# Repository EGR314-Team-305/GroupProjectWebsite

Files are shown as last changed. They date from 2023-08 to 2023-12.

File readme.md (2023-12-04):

---
title: Home 
---
# Home Room Weather Control System

EGR314 Fall 2023  
Professor Nichols  
Team 305  
Members:    
Diego Rodriguez, Uriah Villa, Jack Windle, Nicholas Dunn

<p align="center" width="100%">
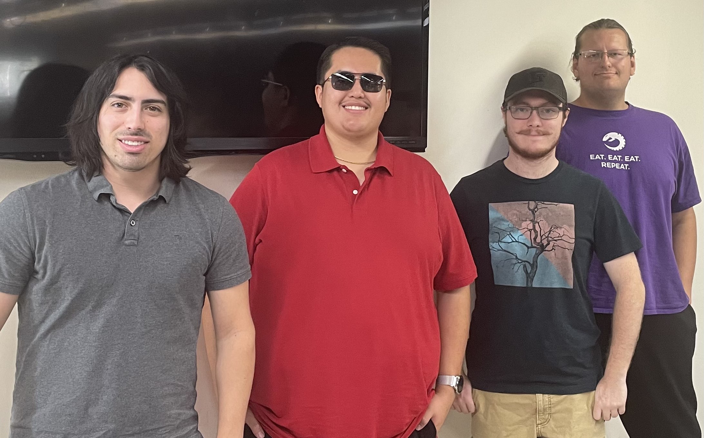
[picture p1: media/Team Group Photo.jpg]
      
</p>

image caption

# Table of Contents
* [Introduction](https://egr314-team-305.github.io/Team305.github.io/#introduction-team-305-semester-project)
* [Team Organization](https://egr314-team-305.github.io/Team305.github.io/#team-organization)
* [User Needs, Benchmarking and Reuirements](https://egr314-team-305.github.io/Team305.github.io/#user-needs-benchmarking-and-requirements)
* [Design Ideation and Final Selected Design](https://egr314-team-305.github.io/Team305.github.io/#design-ideation-and-final-design-selection)
* [Block Diagram](https://egr314-team-305.github.io/Team305.github.io/#block-diagram)
* [Component and Microcontroller Selection](https://egr314-team-305.github.io/Team305.github.io/#component-and-microcontroller-selection)
* [Hardware and Software Implemetation](https://egr314-team-305.github.io/Team305.github.io/#hardware-and-software-implementation)
* [System Verification and Final Presentation](https://egr314-team-305.github.io/Team305.github.io/#system-verification-and-final-presentation)
* [Lessons Learned](https://egr314-team-305.github.io/Team305.github.io/#lessons-learned)
* [Recommendations for Future Students](https://egr314-team-305.github.io/Team305.github.io/#recommendations-for-future-students)
* [Appendix](https://egr314-team-305.github.io/Team305.github.io/#appendix)

## Introduction: Team 305 Semester Project   
  With entering another project based class comes a semester project. For this project, we need to create a custom weather based system that includes multiple sensors and electronical communication. For communication aspects, we intend to use ESP32 two way WIFI communication that we will be taught in class. This will allow the user to view variable data produced by the final product we intend to create. Additional sensors for this project include motion, light, humidity, air pressure, temperature, and many more. We decided to go with light and temperature, as it fits with the project idea that will be stated below. Finally, we will need a motor and motor controller, functioning based on data given by the rest of the system.
  
  Conisidering the part requirements listed above, we decided to make a Home Room Weather Control System. This device will open and close window blinds depending on internal/external factors, light and temperature. The motor will control the blinds, and at what speed they move.
  
## Team Organization

 Our team needs to be organized in such a way that we can effectivly work together and best utilize each of our strengths.  We have defined what each member should be accountable for and how we will work together.  We wish to better ourselves and learn more about the detailed creation of subsystems and circuit boards. 
 
 In order to acomplish this, we devised roles, tasks and responsibilities for each of us to fulfill during the course of the semester. Greater details of this team formation process can be found on our [Team Organization](/Team-Organization.md) page.

## User Needs, Benchmarking, and Requirements  
  When deciding upon which ideals are most important to the customer, we utilized a process similar to reverse engineering. We first collected multiple items similar to our desired project idea, and researched information on them. This allowed us to discover many quailities about the products, such as price, vendor, and many positive and negative reviews about each one. Creating Jamboards after this allowed us to discover similarities about each item that we didn't think about. It was a very interesting [process](/UNBR.md) which took us longer than expected.

## Design Ideation and Final Design Selection 

  After we completed our user needs, we brainstormed any ideas we could think of that complies with our necessary measures. This landed us with three results. The third result we thought about was an automated door opener. Second was a temperature and light controlled fan, which would turn on when it's too hot or lights turn on. Our final design, which is what we chose, is a Home Room Weather Control System. This chosen design would operate window blinds based on external and internal conditions. If it's too bright, blinds close through the use of a motor controlled by the system. If it's too hot inside, it will close as well. If the room is cold, then the blinds will be opened, if external conditions meet specified criteria. Full details can be found on our [Design Ideation](/DIFDS.md) page.
  
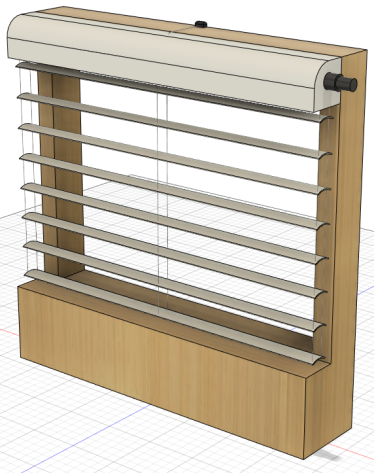
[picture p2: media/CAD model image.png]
image caption
  

## Block Diagram

  With figuring out what project we were going to work on came the process of brainstorming the workflow of the circuit we are creating. Figuring out what we would be using and listing how it would connect with eachother was the primary focus of this portion of the project. Aiming to create a full [Block Diagram](/BD.md) would allow us to visually represent the circuit board in a clear and easy to understand form. 
  
## Component and Microcontroller Selection  

  Once we had a plan for how the subsystems would interact with the main microcontroller, we had to decide on which parts we would utilize. For this process we researched our individual systems and discovered three pieces that would fulfill project parameters. Once this step had been completed, we selected the best of the three options to order, allowing us to finally choose all of our components...Well, most of them.

  After choosing all of our subsystem components, we still needed to choose a microcontroller. Since we are not allowed to utilize the in-class PIC device, we had to find a device similar but fit inside of our requirements. This entailed a descriptive search for a proper chip.

  We also had to make sure our selected components and microcontroller would be properly powered through the embedded subsystem. By looking through the data sheets we were able to design power rails for the project, how we'd get our power, and where each component is placed. 
  
  Please check out our [Component and Microcontroller Selection](/CMS.md) page for further details regarding this process.

## Hardware and Software Implementation

  With our components selected, we had to use the program Cadence in order to generate a hardware diagram. This process was difficult due to our inexperience with the software, as well as some issues with our initial part selections. This resulting schematic for our PCB shows how each chip connects to eachother as well as the schematic for each part. 

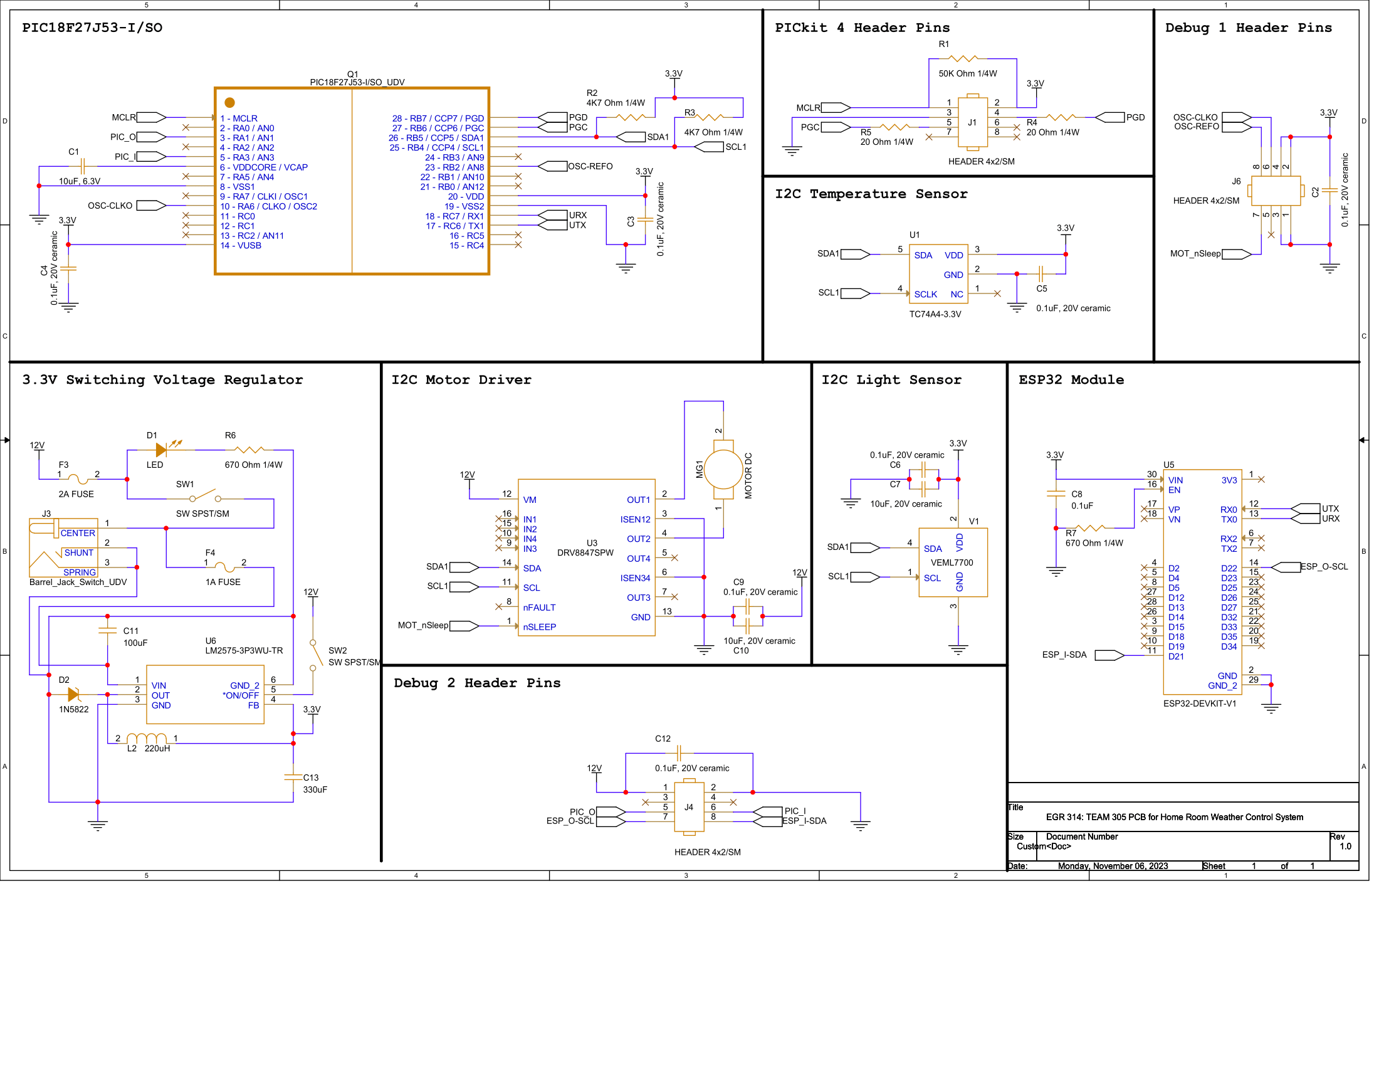
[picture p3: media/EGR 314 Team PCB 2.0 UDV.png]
  

  For the software aspects of our project, we ended up using a program called MPLab X. this software is excellent for coding microcontollers sice we can set aspects of every part we need. Ranging from complex EUSART configs to setting individual pins for input/output data, this program allowed us to complete the code for our project easily and efficiently.

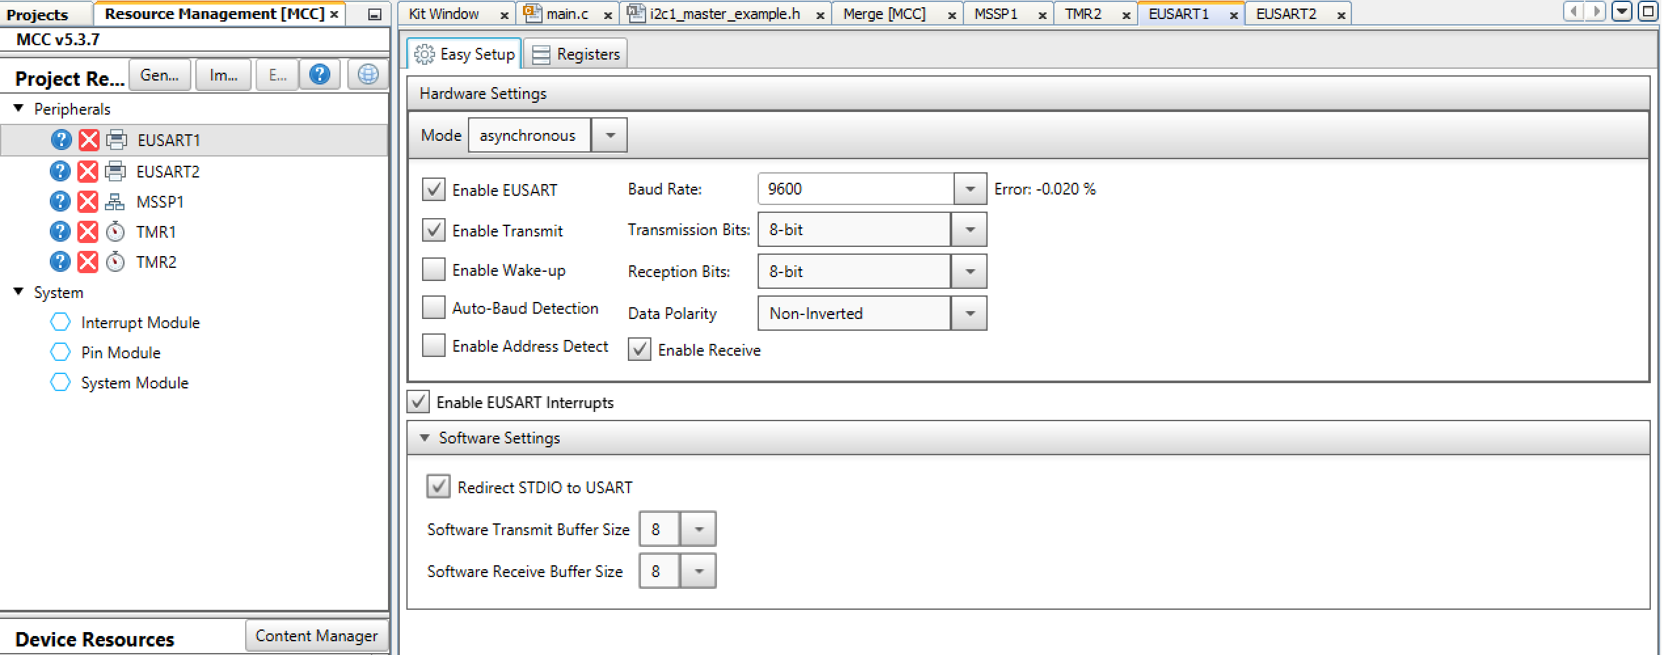
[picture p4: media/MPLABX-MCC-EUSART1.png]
  
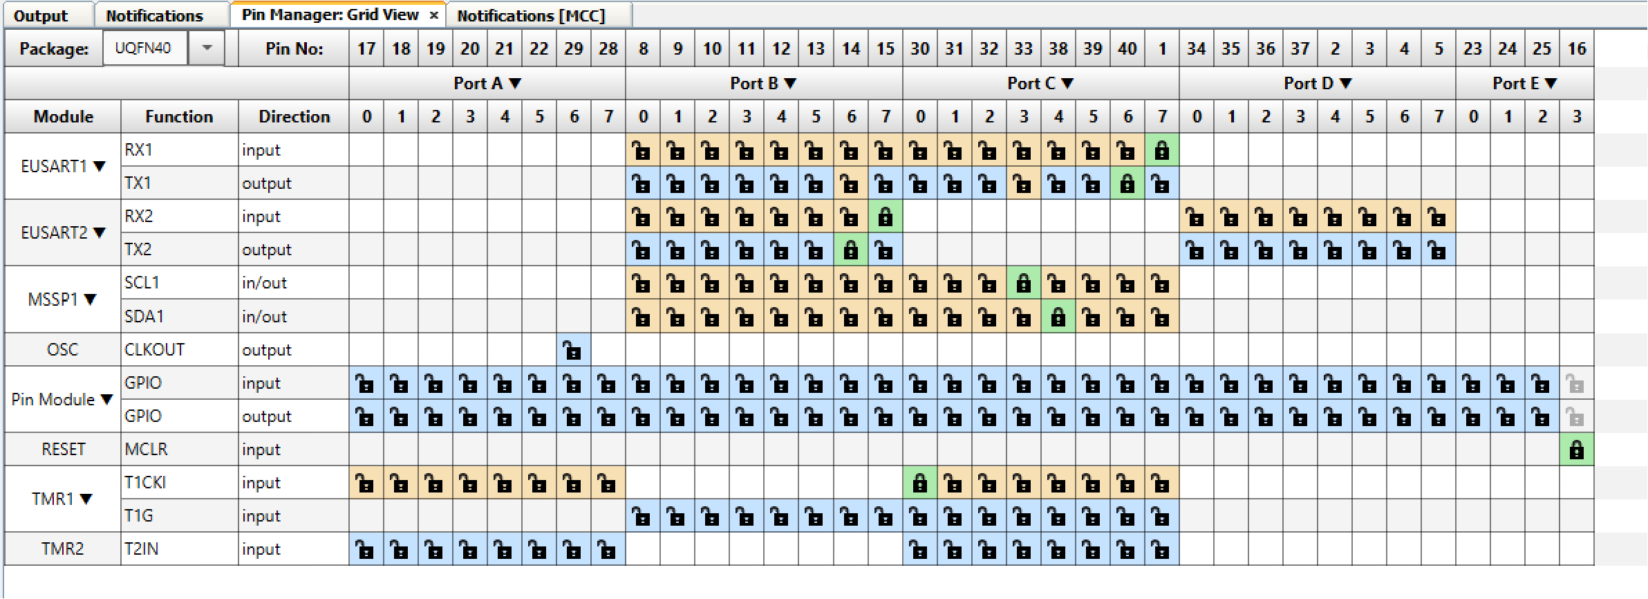
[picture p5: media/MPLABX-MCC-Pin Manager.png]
  

  The software aspects of this project go very deep, and need a vast amount of explanation. To consolidate this info, please visit our [Hardware and Software](/HSI.md) page.

## System Verification and Final Presentation

  One of the last steps for our project is to make sure that each subsystem we created individually can be connected together. This ensures that everyone's project works, and that we worked cohesively as a team.  A final checkoff using the team PCB can be shown in the video below. A full rundown of our debugging and checkoff process can be found in our [System Verification](/SV.md) page.

{% include youtube.html id="lCwTpInNI6Q" %}

Also, in order to finalize our project, we created a full tabletop model which we rigged our working system to. This demonstrates that we not only finished the main course requirements, but went the extra mile to provide a quality and visually pleasing final product.

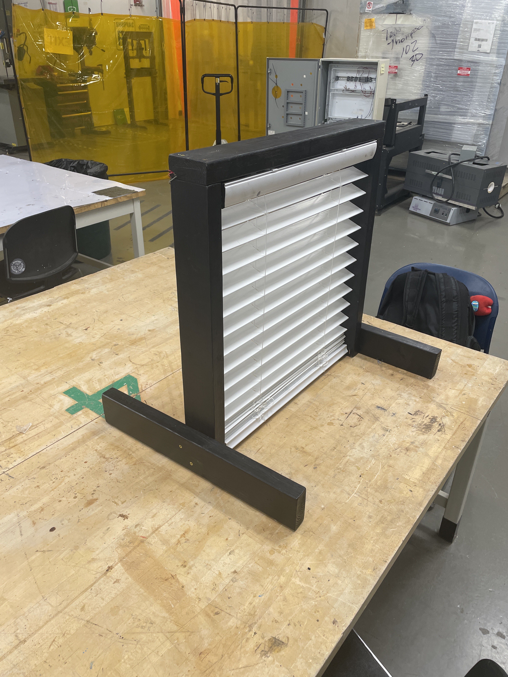
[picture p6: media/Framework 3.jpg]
  

## Lessons Learned

After reflecting on the semester, we noticed that there were a lot of things that we wish we could have done differently while working on this project. Some of these lessons were learned from the previous iteration of this course that were then implemented into this semester in order to develop a successful product within the given time restraints. This section lists 10 of the most important lessons learned by the team over the course of this semester and the previous semester.

The first Lesson was to keep up with the deadlines. The deadlines are not just days to submit the assignments by but also guidelines to what you should have completed if you want to have the project ready in time. Even when a deadline is pushed back, it is important to try and get that done as soon as you can to get back on track.

The second Lesson is order your parts and components as soon as possible. Not having your components will set you back a lot since not having components won't allow you to do any testing. The sooner you have them, the easier it will be identify problems and to fix them. Ordering multiple of each component is important as well since it is very likely you might damage one or two, and also because you will be making more than one pcb/ board.

The third lesson is having good teammates. Make sure to pick teammates that you get along with. This is important since you will be spending a lot of time with your teammates working on the project so something as basic as good chemistry goes a long way. Also make sure that they have a decent work ethic and great communication skills.

The fourth lesson is optimizing your work time. This applies in every aspect within this class whether its working on inidividual assignments or working on the team project. An example of this would be like when we had to do the ESP32 Communication to MQTT communication, as we were doing that assignment we were also implememting that very same code to our Team Project code. Doing simple tandem things like this go a long way since time in this course is an extemely valuable and delicate resource.

The fifth lesson is double checking your schematic. It is a big issue if you print your team PCB and as you're soldering all the components you notice an issue. In most cases you probably won't be able to simply print another one. PCBs take time, so to prevent your team from having a panic attack towards the end of the semester, make sure everything looks good and doesn't have simple mistakes.

The sixth lesson is to use the resources available to you for help. There are many great resources available to help you succeed in this class whether its the proffesor, the TAs, the ASU tutorials website, or even classmates. The ASU tutorials website was particularly helpful when learning how to use Cadence and programming certain components. 

The seventh lesson is to make clear objectives for each assignment with your teammates. The team should split each task amongst eachother to make finishing it more efficient. Making sure everyone knows what they are working on will ensure there is always something being done and is key to success.

The eigth lesson is testing with whatever is easiest. When it came to trying to make our first sensors work, it was a bit difficult to actually test and see what it was outputting with the PIC for our main board since we didn't have MQTT communication at the time and couldnt read a serial monitor. For that reason, we first tested and debugged on the PIC (Nano) that was given to us for the class since it could be connected via usb to a computer and have the values read by the serial monitor. With this, we were able to have functioning code at an early stage for our actual PCB with only minor setup changes needed.

The ninth lesson is give your PCB as much space as you can. Unless your specific project needs to be insanely small, it is a great idea to space out all the components on the PCB as much as you can while staying within the size limit for the class. When soldering and troubleshooting the hardware, implementing this idea will go a long way when it comes to soldering the small components and having all sorts of wires or headers sticking out and obstructing the way. We found out how having so many things close together can give such a hard time while troubleshooting and increases the chances of something shorting.

The tenth lesson is similar to the previous lesson but was important to us enough to make it its own section, and that is make custom pads for headers and other components. We had a couple sensors that needed to go out via headers and wires, but we found out very quickly that premade header pads are very weak due to their small surface area. This minor thing almost gave us a heart attack as we saw important pads being torn off our PCB. If we had just made a custom pad that was slightly larger, we wouldnt have had that issue and would've not only saved us from being stressed out but also time in how long it took us to solve that issue. This experience is engrained into our heads and we will most likely be using larger pads whenever we can throughout our future.

## Recommendations for Future Students

1. It is very important to learn basic 'C' and 'Python' programming languages, particularly 'C' since pretty much all the coding for the class and project is in C. Without this skill, things can get a bit overwhelming and difficult.
2. Watching cadence tutorial videos is a must because Cadence is a decently large and complicated software with a steep learning curb. The earlier you start practicing the better. Don't try to figure it out right before the due dates unless you are trying to feel overwhelmed.
3. It is just as important to actually get cadence installed, at least one week in advance (the earlier the better). It is a big file and can take a couple of hours to install. We have also found it doesn't install so easily on certain computers, so trying to install from an early stage will allow you to figure out any difficulties you are having with the installation.
4. A big "must" is asking for help as soon as it is needed. There are many new things and topics in this class that can be quite tricky to understand and asking for help is the fastest and easiest way to get on track. Others are most likely having the same issues as you so don't feel like its just you.
5. Planning everything ahead is probably the most important on this list. Planning ahead is vital since things move very quickly in this class and lack of a plan will lead to a lot of both major and minor oversights. An example of this is figuring out the PCB tolerance requirements for the lab. Not thinking or knowing something like this ahead of time can caus you to have a PCB that will get rejected by the lab and set you back a day or two. Or another example could be in designing the PCB where you need to plan ahead and fully understand what components you are using and how they will interact with eachother and in actual use. Don't simply design the minimum requirements and then later realize you forgot to add headers to program the Microcontroller or a pad for the the power supply. In general, planning ahead helps avoid mistakes and have an idea of what has to be done at all times.

## Appendix
* [Appendix A: Team Organization](/01-team-organization.pdf)
* [Appendix B: User Needs, Benchmarking, and Requirements](/02-user-needs-and-requirements.pdf)
* [Appendix C: Design Ideation](/03-design-ideation.pdf)
* [Appendix D: Block Diagram](/media/Block-Diagram.drawio.png)
* [Appendix E: Component Selection](/Comp.pdf)
* [Appendix F: Microcontroller Selection](/05-Micro.pdf)
* [Appendix G: Power Budget](/Power_Budget_v2.pdf)
* [Appendix H: Hardware Proposal](/Cadence_Schematic.pdf)
* [Appendix I: Checkpoint 1 Youtube Powerpoint Presentation](https://youtu.be/rEpy6BaRJAM)

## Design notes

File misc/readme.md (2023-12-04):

Miscellaneous files for examples, help, or templates and other random files the project uses that dont fit in any current folder

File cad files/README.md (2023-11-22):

This is for the elctronic and physical models of our project. Example: fusion 360 cad files, and cadence pcb files

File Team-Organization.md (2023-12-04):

---
title: Home 
---
 
# Team Organization

  Entering another project based class, our team needs to be a well functioning machine where every aspect works. Resulting in the team Charter, we developed a page of expectations for us to follow. This includes but is not limited to teamwork, communication, quality of work, and much more. 

  Our mission statement is that we want to learn about the detailed creation of subsystems and circuit boards. Through the process of creating a home automation system focusing on simplicity and reliability, we can create a system of multiple functioning pieces. Although sometimes complicated, creating this system of subsystems will allow us to learn and demonstrate growth in the field of engineering
  
  Ensuring that all members of our group complete their share of work to a standard sufficient with our level and expectations, all members of our team have agreed to and will follow the examples mentioned in the original document, found in [Appendix A.](https://egr314-team-305.github.io/Team305.github.io/01-team-organization.pdf) 

  With finding the members of our team, we initially went for friends first. Although this is usually against what we are supposed to do, each of us brought something uniquely strong to the group. Jack brought a heafty amount of experience in coding, resulting in him being named Head Coder. Uriah has made circuit boards in the past, leading to his role as our PCB (Personal Circuit Board) Designer. Diego has in depth knowledge of the 3D modeling program Fusion 360. This allowed him to easily take the role of our Head Designer. Nicholas, as well as most of the others, was found to have knowledge of all these main tasks, but not enough experience to outclass anyone. Thus, with his knowledge of the inner working of websites, he was named Website Designer.
  
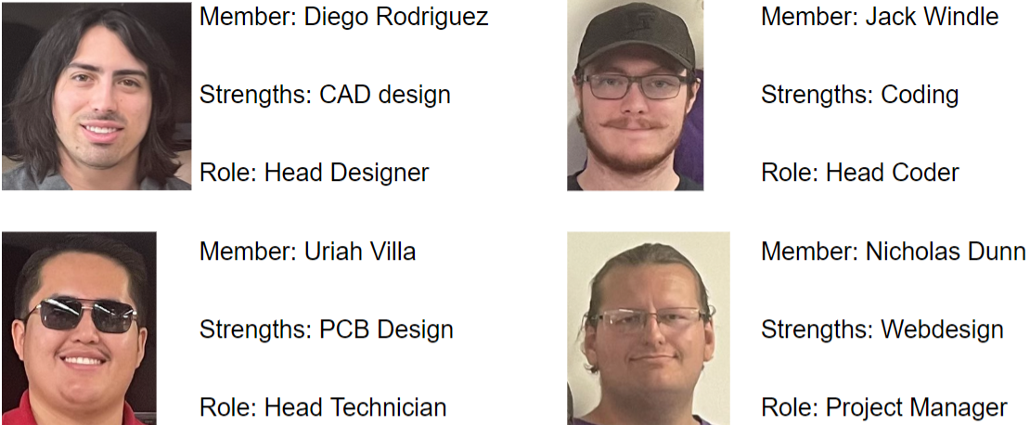
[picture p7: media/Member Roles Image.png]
image caption


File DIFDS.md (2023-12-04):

---
title: Home 
---

<h1>Design Ideation and Final Design Selection</h1>

<p> After completing our user needs, we brainstormed any ideas that complied with our necessary measures. This landed us with three results. The first idea was a home automation system that would open and close blinds depending on the temperature and brightness in a room. The Second was a temperature and light-controlled fan, which would turn on when it was too hot or lights turned on. The third result we thought of was an automated door opener that senses when someone is near and will open the door. After much consideration, the Home Room Weather Control System made the most sense to us. This idea would be best since it needs the exact number of components and sensors to make it work for the requirements of this project, unlike the other ideas. 
  
This project would operate by reading the internal conditions of a room to control the blinds. If it is too bright, the light sensor will close the blinds using a motor controlled by the system. If it is too hot inside, it will close as well, and if the room is cold, then the blinds will open. The wireless control will allow the user to have complete remote control of the blind setting for their convenience. The blinds will have presets and a close/open increment button for simplicity. The blind settings will also have an automatic mode that can be set so the blinds will open and close to certain levels depending on the time of day and/or amount of light. The blinds and window will contain all the parts, requiring only a one-time setup process. Also, the unit will plug into standard US AC wall power, allowing it to be used anywhere an outlet is nearby. In summary, it is designed to control blinds intuitively. </p>
<br>

<p align="center" width="100%">
      
</p>
  
<br>

<p> This chosen project allowed us to satisfy the project requirements. Next was a case of designing our subsystems and figuring out what parts we would use. This entailed creating a block diagram of how our subsystems would interact with each other and what components we would need to choose.

We went through a brainstorming phase to develop the product we are now working on. Our brainstorming for this project was brief since we unanimously agreed on the result. We began brainstorming ideas, and Jack thought we should do a home automation system that would utilize sensors to control house appliances and features. We, as a group, were instantly on board with this idea. </p>
<hr>

<h2>Automated Blinds</h2>
<p>
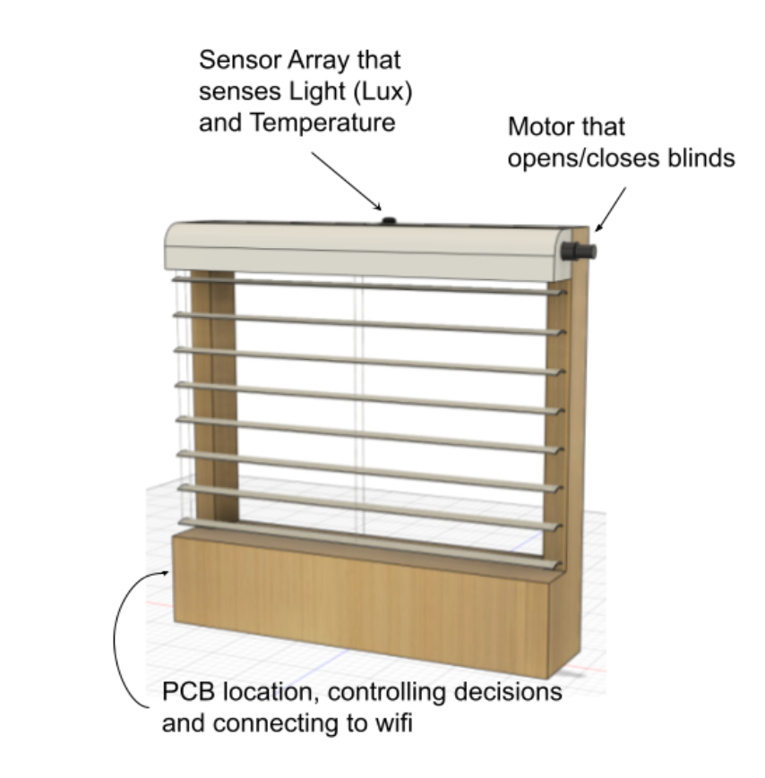
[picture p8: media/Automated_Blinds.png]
 Home automation is a vast subject, so we devised three ideas to fit the topic. The first was a system using sensors to open or close blinds and read the sensors' values over the internet. The wireless control will allow the user to have complete remote control of the blind setting for their convenience. The blinds will have presets and a close/open increment button for simplicity. The blind settings will also have an automatic mode that can be set so the blinds will open and close to certain levels depending on the time of day and/or amount of light. The blinds and window will contain all the parts, requiring only a one-time setup process. Also, the unit will plug into standard US AC wall power, allowing it to be used anywhere an outlet is nearby. 
</p>
<br clear="left"/>
<hr>

<h2>Automated Fan</h2>
<p> 
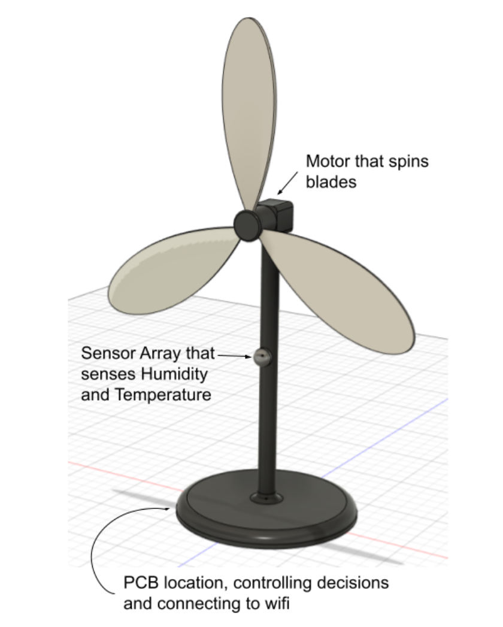
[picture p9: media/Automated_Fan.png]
 The second system used sensors to turn on a fan/motor. This design allows the user to set a fan speed to best match their preference with presets they can choose or a faster/slower button for fine-tuning adjustment. The sensor array will allow the fan to tell if the temp or humidity is high and automatically turn on to create a draft that helps increase the room experience. The Wi-Fi control allows the user to control the fan remotely without needing the user to adjust the settings on this "smart fan." 
</p>
<br clear="right"/>
<hr>

<h2>Automated Door</h2>
<p> 
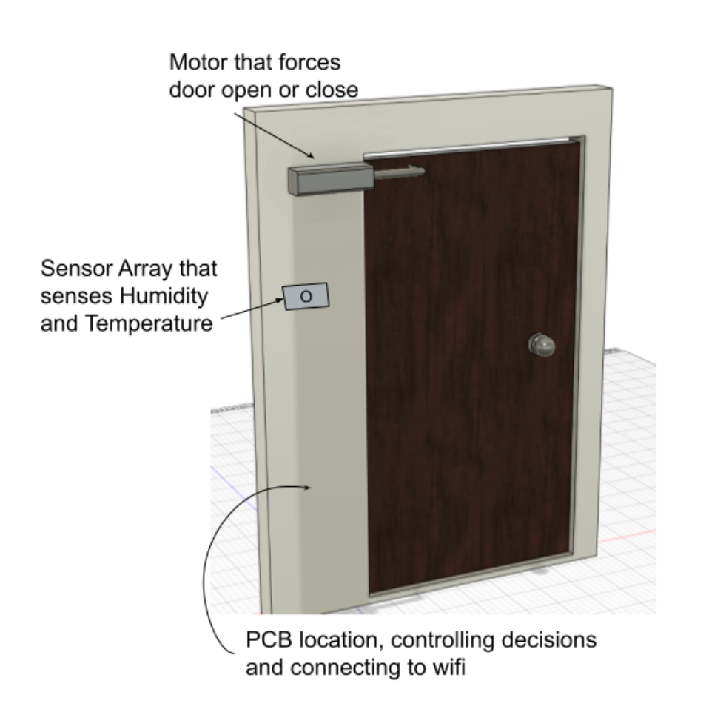
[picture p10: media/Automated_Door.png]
 Lastly, the third idea was an automatic door using sensors to open or close. The door will automatically open wirelessly at the press of a button, helping those who might not otherwise be able to open the door physically. Examples include disabled users, those carrying many items, or those not wanting to touch the door. The door can also control the closing for the same reasons and to prevent slamming. The sensor array can have the door open/close to allow/prevent airflow through the rooms, even controlling the amount the door is "cracked" based on the temp/humidity. These settings can be preset or dynamically changed by the user. 
</p>
<br clear="left"/>
<hr>

<p> After making mock CAD models and discussing all the ideas, we unanimously agreed that the automated blind opening system would be the best for our project because it is the most useful and efficient in everyday life. We then discussed the details to decide which sensors would make the most sense and our experience. After a brief discussion, we decided on this system functioning on the subsystems of a motor/motor controller, a light sensor, and a digital thermal sensor. </p>

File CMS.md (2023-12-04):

---
title: Home 
---

# Component and Microcontroller Selection

## Beginning Approach

We read the project requirements very closely to ensure that we were picking components that were allowed to be used for our design. While doing research on components, we focused on parts that incorporated detailed datasheets as well as immediate accessibility. With an experience of struggling to obtain certain parts, we wanted to be certain that we had quick access to start testing and debugging our current concept selection.

We began our search with components we have worked with in class since we are familiar with them. We first listed the pros and cons of the parts we used in previous assignments, then looked for similar components that would offer solutions to the cons we had recorded. We would choose a few components with different strengths and weaknesses for subsystems that required a part not used in a previous assignment.

Once our possible choices were listed, we chose the best option, prioritizing ease of use, such as a package size manageable enough to hand solder and accessibility to external resources.

## Temperature Sensor
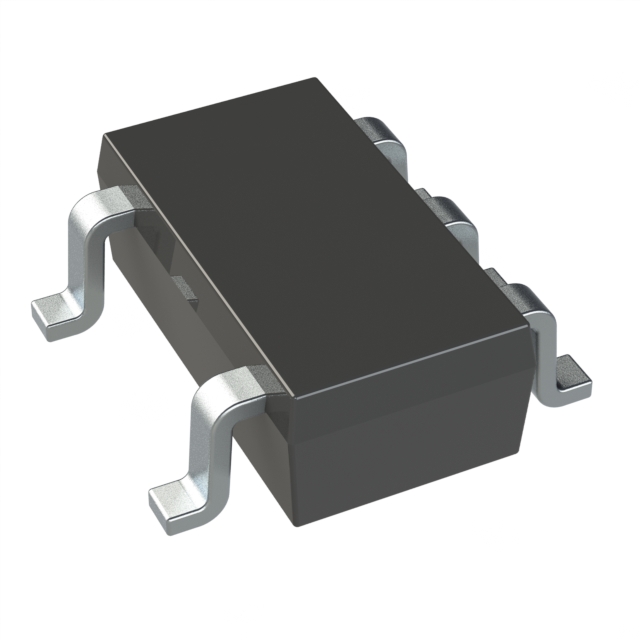
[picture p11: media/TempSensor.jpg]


The TC74A4 temperature sensor is a serial sensor manufactured by Microchip. It can measure temperatures between -40C and 125C and outputs data using I2C. The voltage supply range for this sensor is a minimum of 2.7V to 5.5V. We were given this sensor in class, and there was information on it provided which made the selection of this component an easy decision. This sensor is also a very manageable size, which is essential since it will be surface mounted onto the PCB.

## Motor Driver
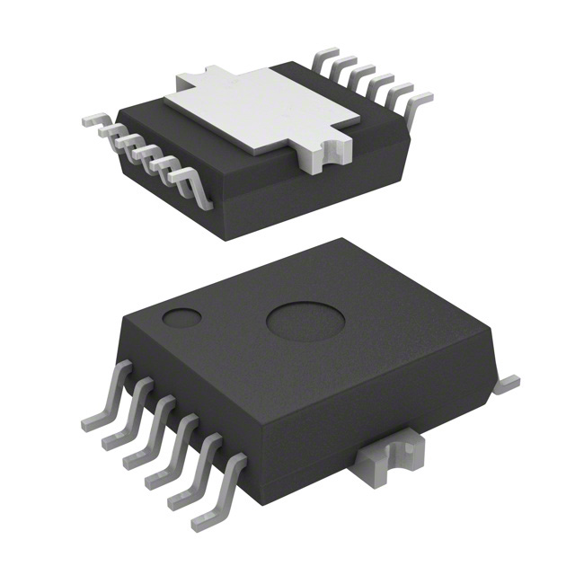
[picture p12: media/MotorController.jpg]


We ultimately decided to go with the DRV8847SPWR motor driver manufactured by Texas Instruments. While deciding on this component took a bit longer and extra steps than the other components, we mainly stuck with it because it uses I2C to communicate. All of our components are I2C, so to stick with the elegance of connections that come with I2C, we decided to go with it. 

## Motor
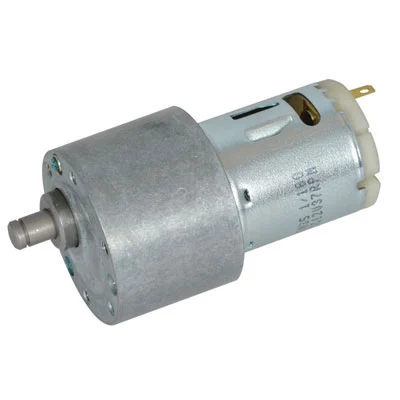
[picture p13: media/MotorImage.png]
image caption


We instantly went with a 12V DC Reversible Gearhead Motor when choosing the motor. On top of it is a motor that is very accessible to us through ASU; we have worked with these motors in the past, and proved to be very reliable and easy to work with. Another prominent feature of this motor is its notable torque, which we knew would be more than enough for our project that would require consistently rotating blinds. 

## Light Sensor 
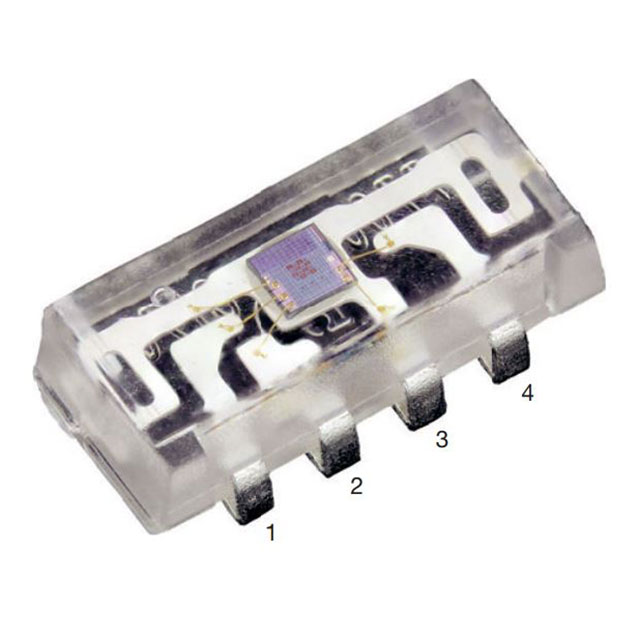
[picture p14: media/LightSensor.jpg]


The light sensor we chose was the VEML7700-TT manufactured by Vishay Semiconductor Opto Division. It communicates through I2C, the same as all of our components. The main factors that made us go with this sensor were its excellent price, availability, and sensitivity. The sensitivity of this sensor is incredibly customizable and precise, which is essential for getting our system to work efficiently.

## Voltage Regulator
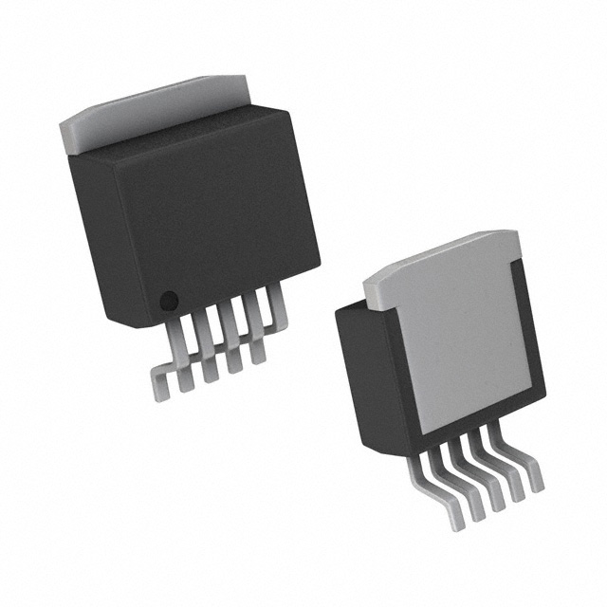
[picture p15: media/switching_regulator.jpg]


The LM2575S-3.3 is very accessible and easy to understand with the provided datasheets found online. The regulator is easy to implement into our system and has many applications from others online and through the datasheet that we can interpret, and we could design it into our project.

## Microcontroller
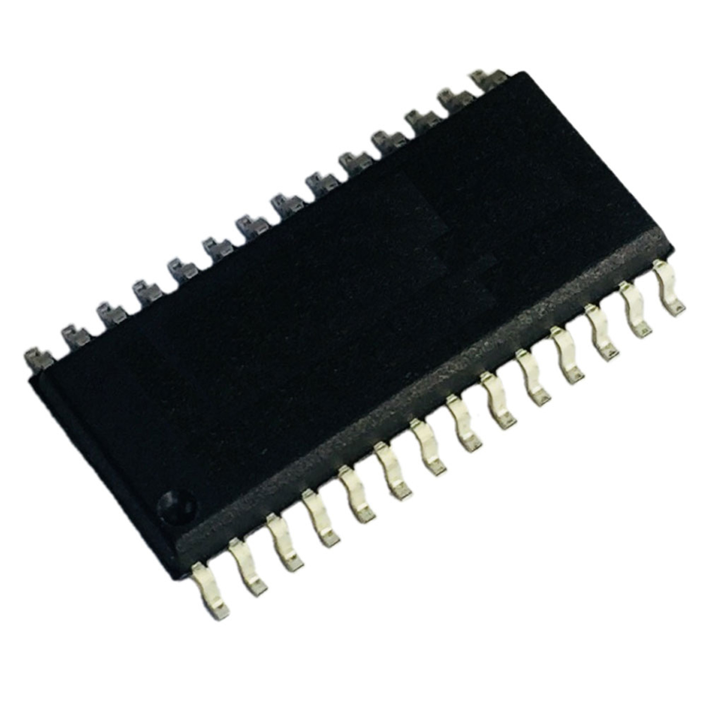
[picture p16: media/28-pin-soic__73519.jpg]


The microcontroller we used for our project is the PIC18F27J53-I/SO manufactured by Microchip. The microcontroller selection was a critical decision to make, which is why we considered many factors. This microcontroller is very similar to the microcontroller we had been using in class, which is very nice since we practically had a bit of experience with it. It would make the set-up much more accessible. It also didn't have too many pins and was a decent size, which would help with the actual organization and soldering of the board. It made it relatively simple to solder to our PCB and ensure a solid connection, which would've been much more difficult had we chosen a smaller-sized PIC or one with more pins. It met all the requirements for our project and we did not struggle at all with the set-up, so it is safe to say it was a solid choice.

 After selecting our components, we needed to implement them into our central system. Each member took their respective components to test and get working. We compiled all of our data into three separate documents: [Component selection](/Comp.pdf), [Microcontroller selection](/05-Micro.pdf), and [Power budget](/Power_Budget_v2.pdf), to better view all available info on our parts.

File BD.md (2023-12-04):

---
title: Home 
---
 
# Block Diagram

  After figuring out what project we would work on, the process of brainstorming the workflow of the circuit we were creating came. Figuring out what we would be using and listing how it would connect was the primary focus of this portion of the project, as well as determining who would be responsible for each subsystem. Aiming to create a complete block diagram would allow us to visually represent the circuit board in a clear and easy-to-understand form.

  In this process, we saw that course requirements determined we would use a Microcontroller to ESP32 communication to transmit data through WIFI. With this part selected by default, Nicholas was put in charge of getting the ESP32 to communicate with the microcontroller we selected and a Wi-Fi-enabled device, which, in our case, was a smartphone.
  
  Other components in our base requirements are two sensors and a motor controller. The motor controller, as its name implies, controls a motor through external data given through the central system of the group. Developed by Uriah, this subsystem relies on data fed to the design from the other two subsystem sensors. Uriah was the lead designer of the voltage regulator for the system and for the motor driver to be controlled through I2C.

  Diego and Jack would select their sensors for our remaining two components, with approval from the professor. Selecting a temperature sensor, Diego utilized a component we were familiar with to optimize time on the project. Focusing on our last sensor, Jack challenged himself with a light sensor. This component was challenging to wire and implement, thus leading to a unique project version. With Diego as the head of the temp sensor subsystem, he got the temp sensor to communicate with the microcontroller through I2C and was the lead in the code of the main project. With Jack as the lead designer of the light sensor subsystem and communicating through I2C to the microcontroller, he also became the co-lead in developing the main code for the project. 

   Later in the project, we split much of the work into different sections, with Uriah designing, building, and testing the team PCB that was milled and printed from JLPCB. Once the board was fully assembled and tested for wiring mistakes or shorts. Jack and Diego went through the debugging process with the software and checked that they could read the serial values received from the temp and light sensors. When our board was finished, and the code was ready, Nick was able to build the physical structure of the blinds, and Diego was able to 3D print the enclosure for the team board and sensors.

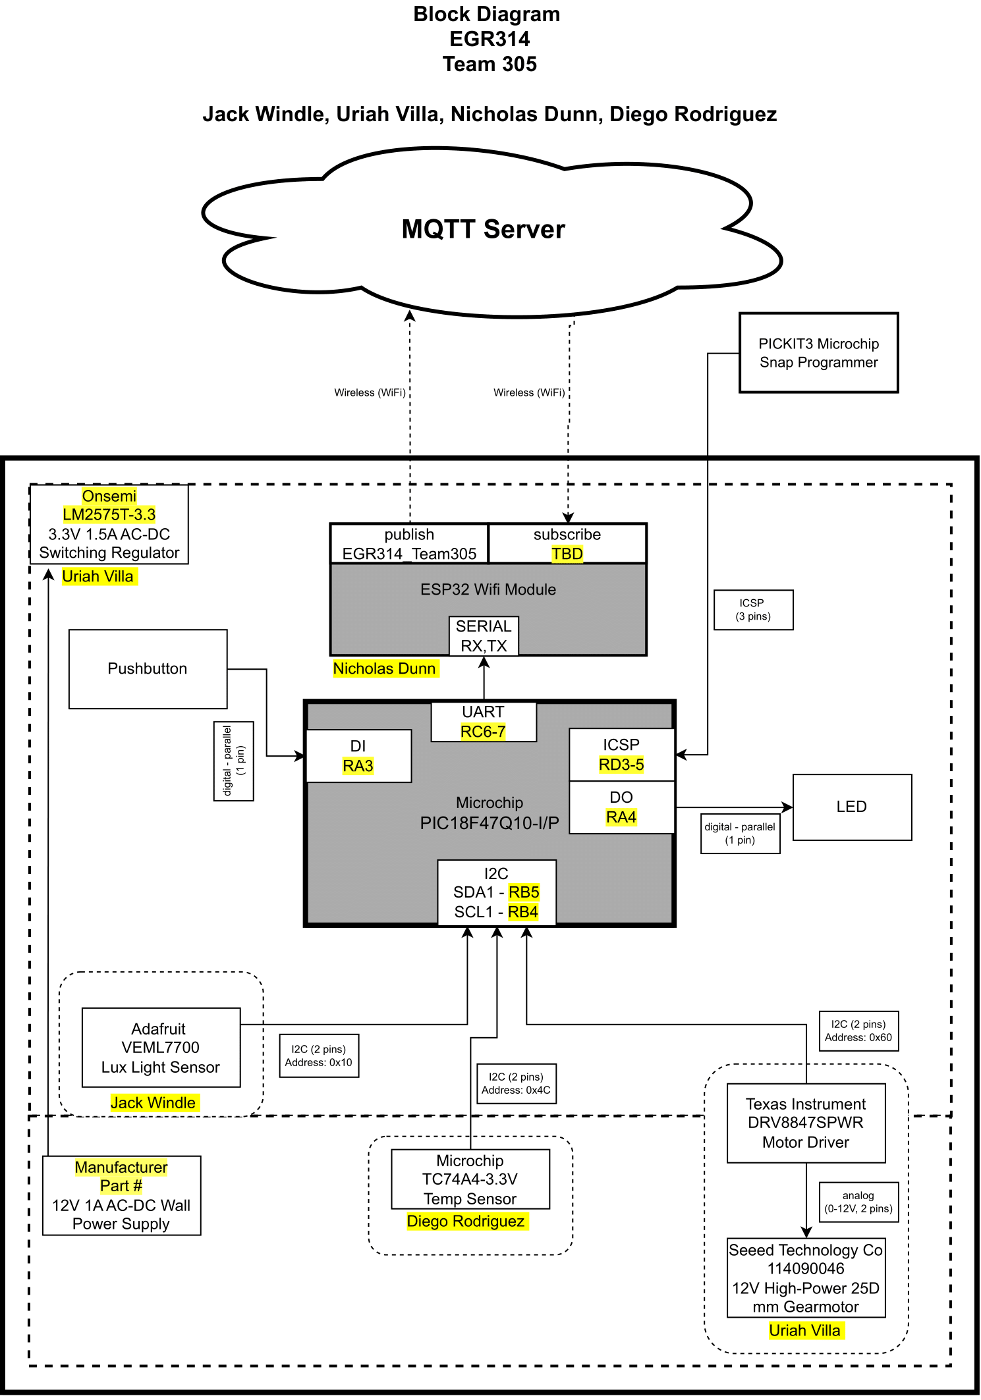
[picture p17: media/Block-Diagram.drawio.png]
image caption


  In the above block diagram, we listed every part of our project, retroactively labeling each block with port information, part numbers, communication types, and additional information necessary for us to understand each segment. We also added more details about power, voltage regulation, and control buttons. This allows us to visualize the project from a fundamental view that most people can read and understand. Consolidating our unique subsystem information like this also allows us to view each other's subsystems and get knowledge of them without doing the initial research each member had to do.
  
* [Appendix D](/media/Block-Diagram.drawio.png)

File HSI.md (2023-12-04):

---
title: Home 
---
 
# Hardware Implementation

image caption
Schematic View

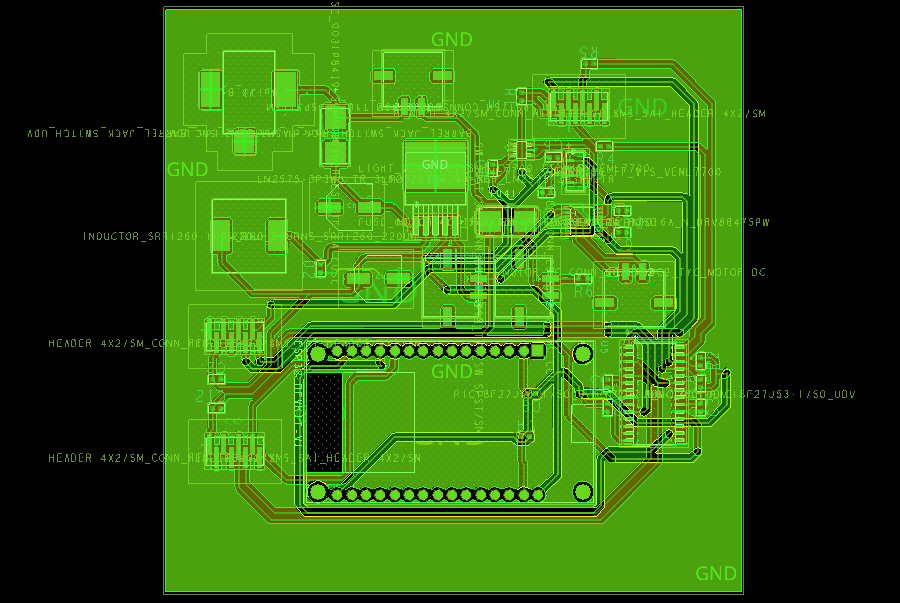
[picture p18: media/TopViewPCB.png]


PCB Top View

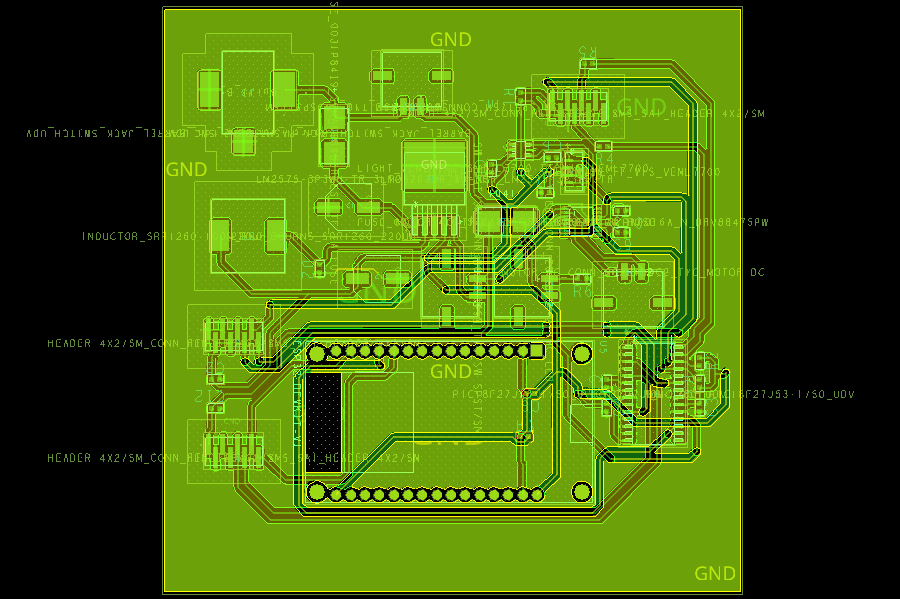
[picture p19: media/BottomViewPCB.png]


PCB Bottom View

# Functionality

The whole design is based on the idea of having a sensor for two of the factors that determine how hot a room is, which are temperature, of course, as well as light. These sensors would be able to read the temperature and light in the room and would be able to control the blinds depending on how high or how low those values are. 

Our schematic consists of our Voltage Regulator that takes 12V and makes sure our whole circuit runs on 3.3V, Microcontroller that controls all of our other components, ESP32 that allows us to communicate with our Microcontroller via the internet, Temperature sensor, Light Sensor, and Motor Driver that controls the motor. This schematic will enable us to connect all of our components and have them communicate to make our Home automation device function as it should. The components, such as the sensors and the motor driver, are I2C, meaning they all connect to the same pins on our Microcontroller. This makes our PCB significantly more simple and minimalist. 

# Improvements for the Future

We came upon multiple challenges when it came to hardware. The main challenge is the header pads on our PCB. Header pads, by default, are tiny and fragile, and we found out just how fragile they are while working on our project. Despite being soldered solidly, the pads for multiple headers got torn off by being touched. This caused many difficulties and forced us to solder external wires through many parts on our board and much hot glue to ensure more things would not tear off. This could have easily been avoided by designing custom pads for the headers with more surface area to ensure they could not be torn as quickly as they did.

Another change that we would have made is adding more headers. We quickly realized we were running out of connections for certain things as more were damaged or torn off. Adding more headers would have helped since it would give us a "Plan B" from when things got damaged. Having a backup plan is always a good idea when designing a PCB, and we definitely will do it for our next project despite having gotten away with it this time. 

# Software Implementation

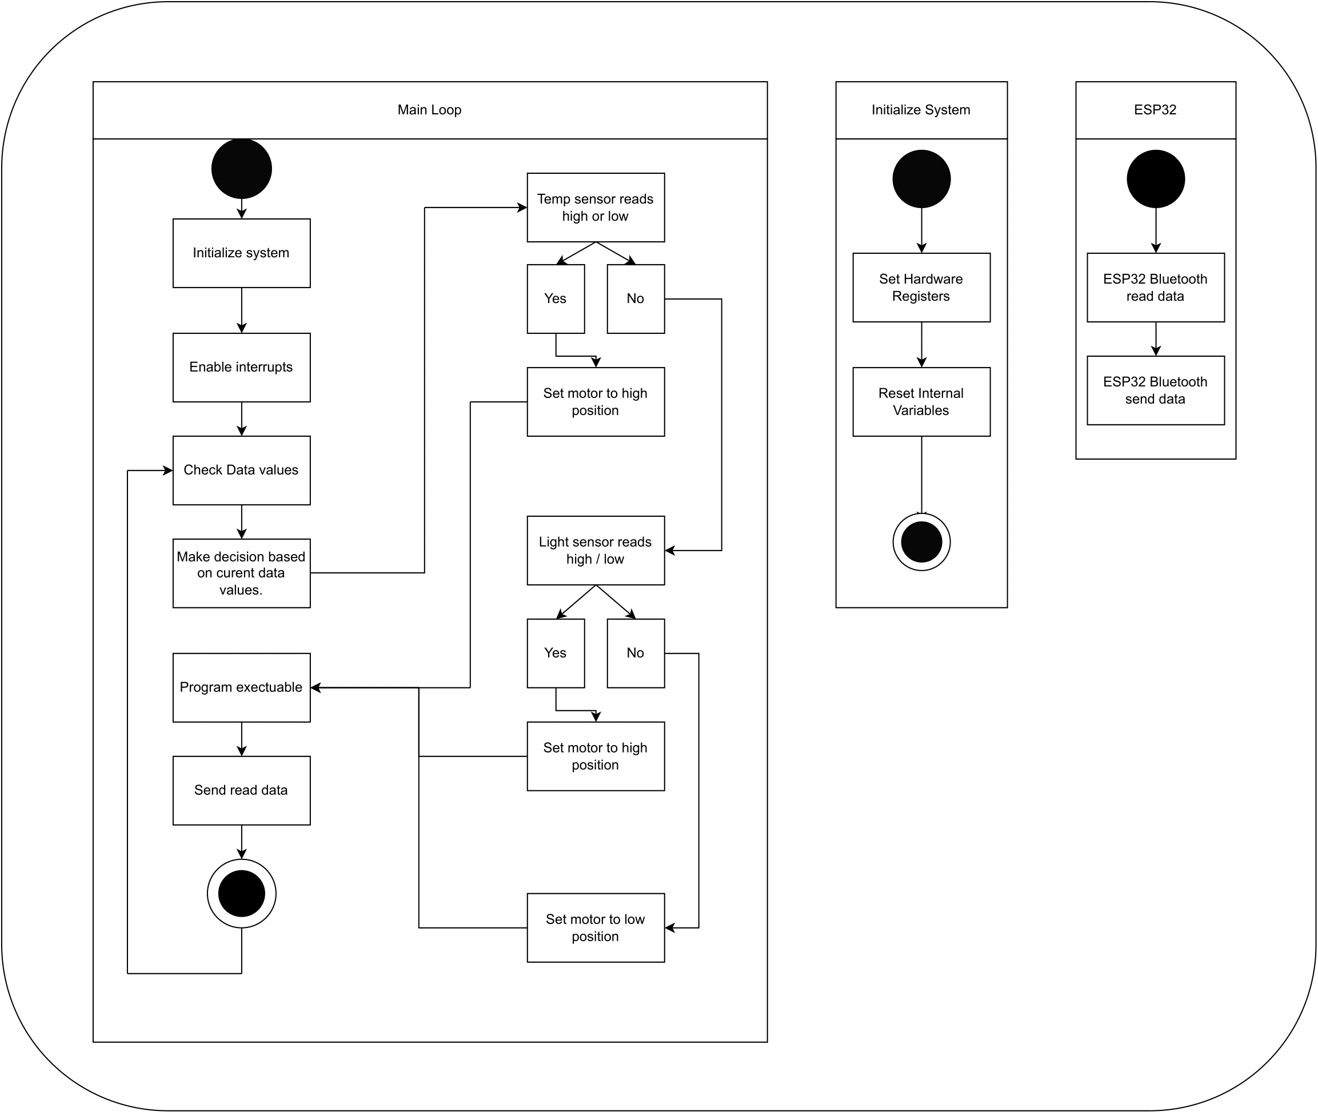
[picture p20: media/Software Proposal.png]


# What we learned/ would change
Reading the datasheet for each component is the best advice regarding this project. Some of the components had rather long data sheets with more information than we wished they had, so to get around this, we took a shortcut and went straight to the coding section. That was the biggest mistake. Datasheets give all the information needed, and we learned that importance the hard way. It took a long time to figure out the coding and what specific things did. The time we lost trying to figure out the coding registers and order of everything by only reading the coding section was much more than if we had just read the whole datasheet. 

Regarding actual coding and organization, we could do a decent job. Everything worked well in the software aspect on the first try, which was a lovely surprise. The way we were able to do that was by planning. We began our code by declaring all the registers from our components, which would initialize and enable them to communicate with our microcontrollers. After that, we made functions for each of our components since each had its own set of equations or unique way of sending out data that required a specific conversion or order of operations that could be made through functions. These first two steps required an in-depth search and analysis of the data sheet to complete successfully. We attribute our success to doing our code work on the first try, to start the code once we understood all our components and the setup each would need. It truly helped us plan and, from the beginning, start on the right track. We then ensured that we initialized anything needed at the beginning of our main code. The main loop was straightforward; mostly, I2C reads, writes, and calls the functions we had made at the beginning. The rest used Printf to use our ESP32 to MQTT communication to print out the data from our sensors.

# 5 Biggest Changes
1. Organizing the registers for our components
   * This change helped us mostly in readability and ability to differentiate the registers quickly.
2. Commenting on every function and variable
   * Since the coding was done over a long period, we often forgot why we wrote things the way we did towards the beginning, so we started commenting thoroughly
3. Using delays generously
   * We found out very quickly once we started running the code that things took some time to read or write, which would make them work a bit inconsistently. We were able to improve this and ensure every value got read correctly by adding multiple delays throughout all of our code.
4. Minimizing Printf
   * After we had started testing, we realized that specific values were not being shown in our MQTT server. ESP32 communication likes it when you send fewer things to print. We then had to reduce all of our Prints and only keep the essential values that needed to be read.
5. Two different codes for different sensors
   * When it came to the actual application of our project, we realized that it would be very unrealistic and would make testing much more difficult to have one code that would use specific conditions from both our sensors to get the motor to react. We decided to make two codes, one that would get the motor to close the blinds(spin the motor) with the temperature of the room and one that would do the same but based on the brightness. This made testing much more accessible and will work better in real life.

# MPLAB X IDE Setup  
     
image caption

Eusart 1
* Enable Eusart
* Enable Transmit
* Enable Recieve
* Enable Eusart Interrupts
* redirect STDIO to USART
* Everything else Default

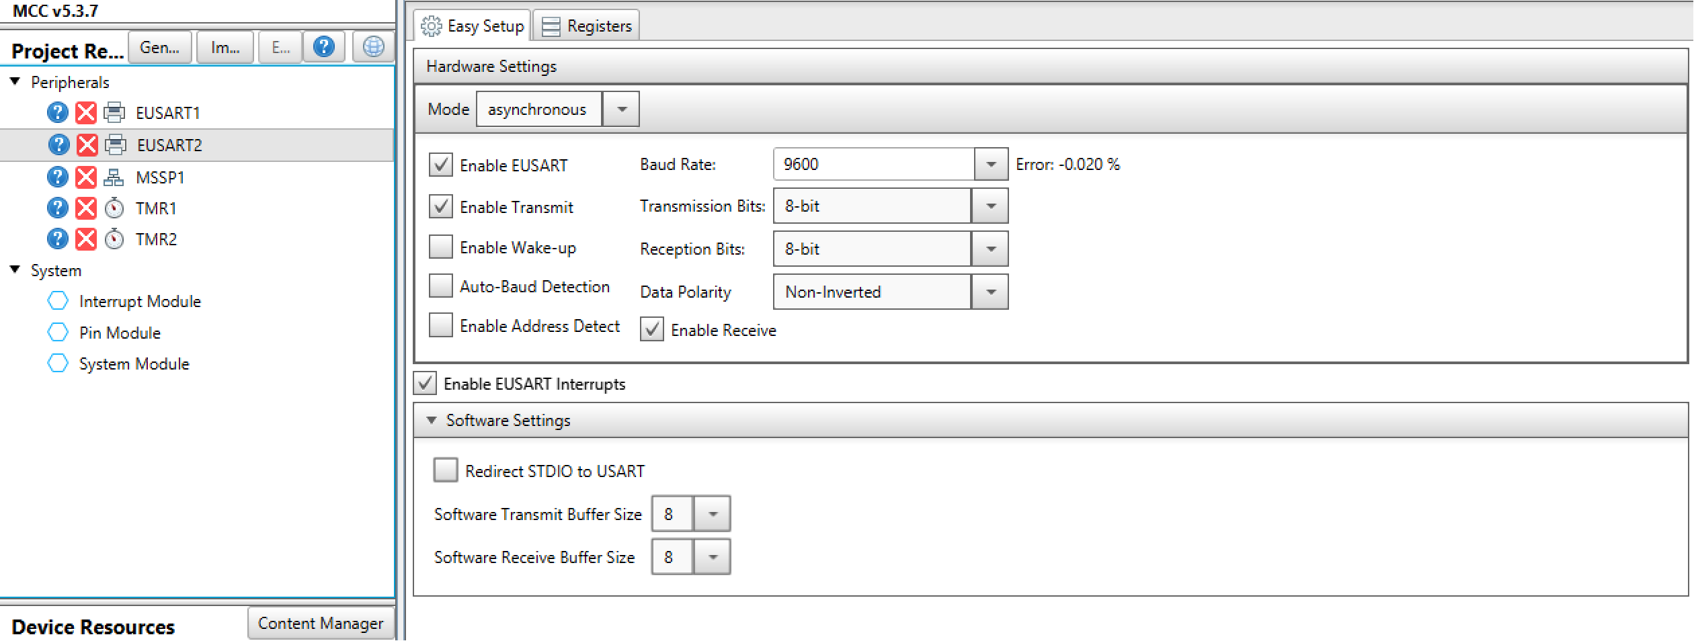
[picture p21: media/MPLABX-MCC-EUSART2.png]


Eusart2
* Enable Eusart
* Enable Transmit
* Enable Recieve
* Enable Eusart Interrupts
* Everything else Default

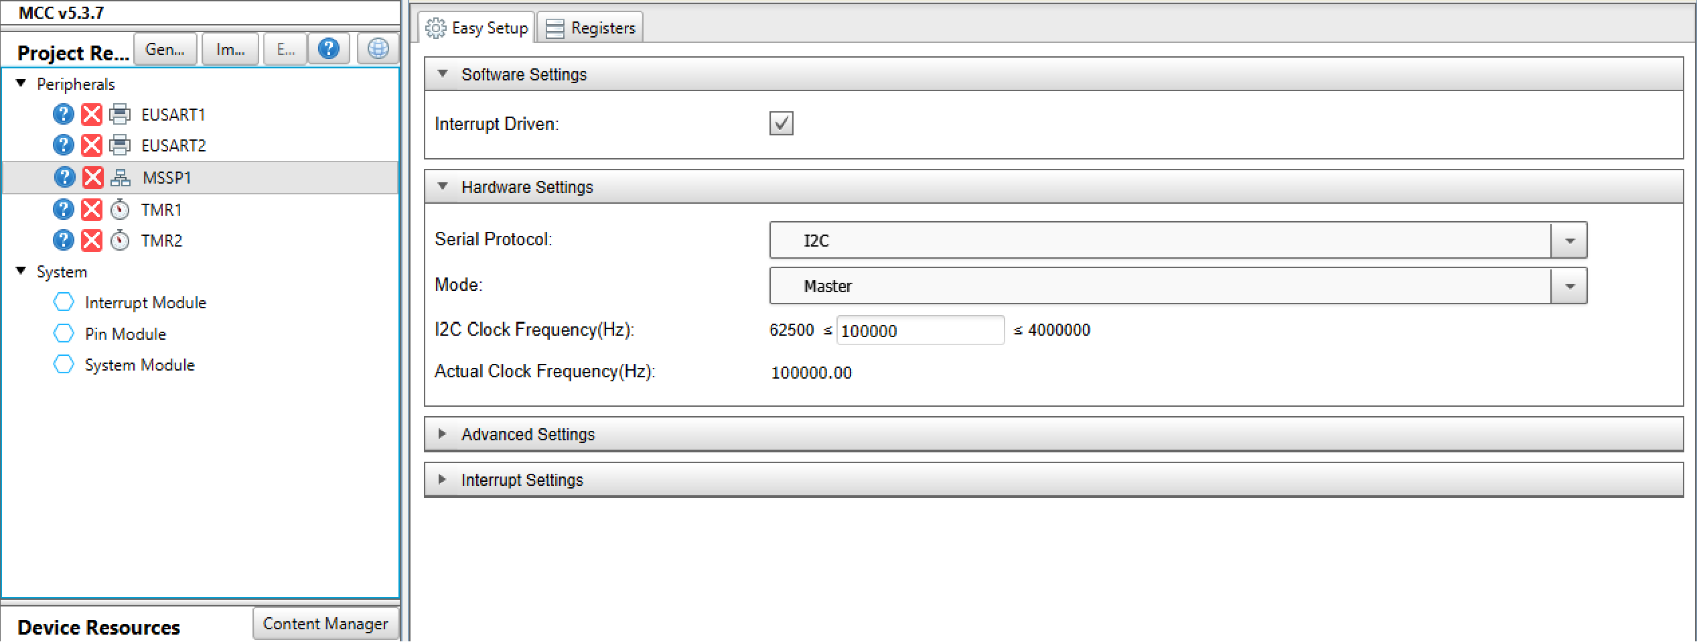
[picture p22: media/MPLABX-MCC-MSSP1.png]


MSSP1
* Interrupt Driven
* Serial Protocol: I2C
* Mode: Master
* Everything else Default

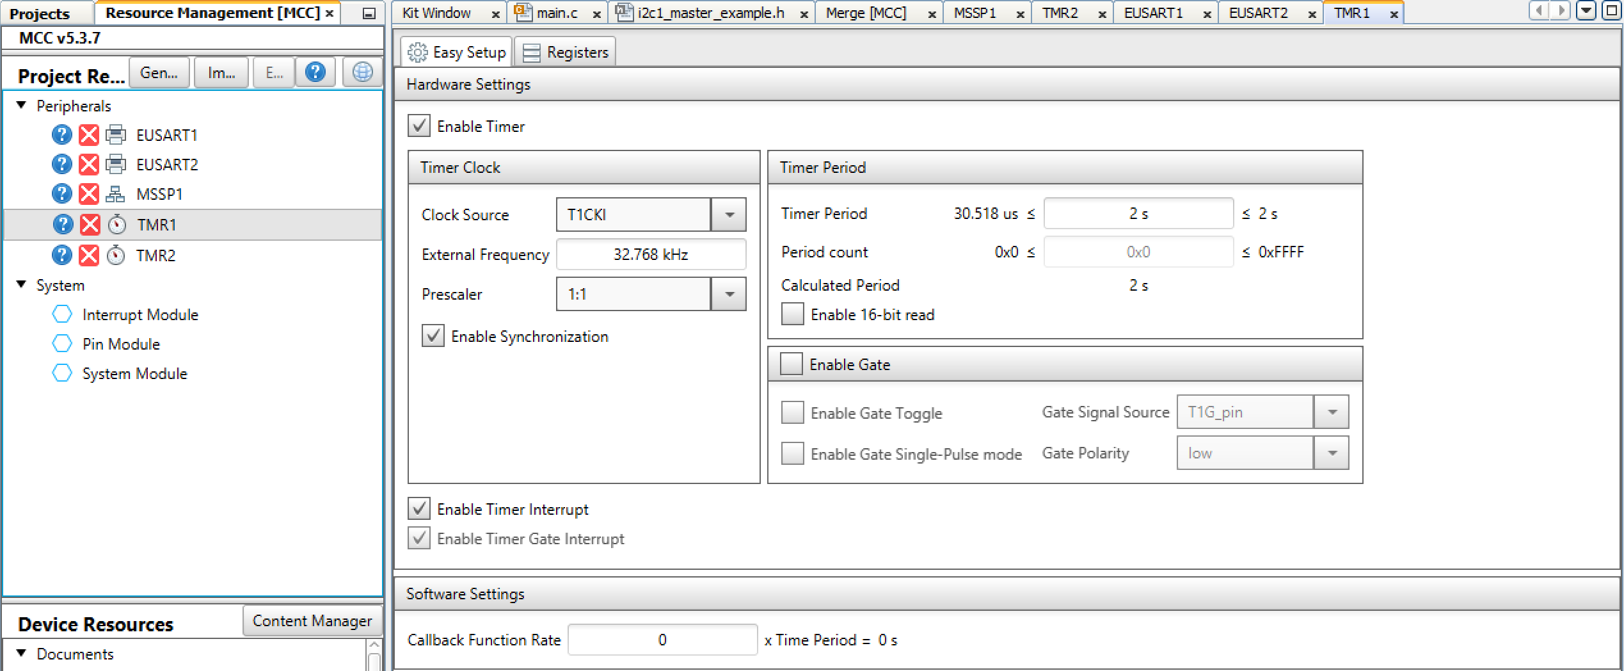
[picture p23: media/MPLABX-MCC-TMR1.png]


Timer 1
* Enable Timer
* Enable Timer Interrupt
* Everything else Default

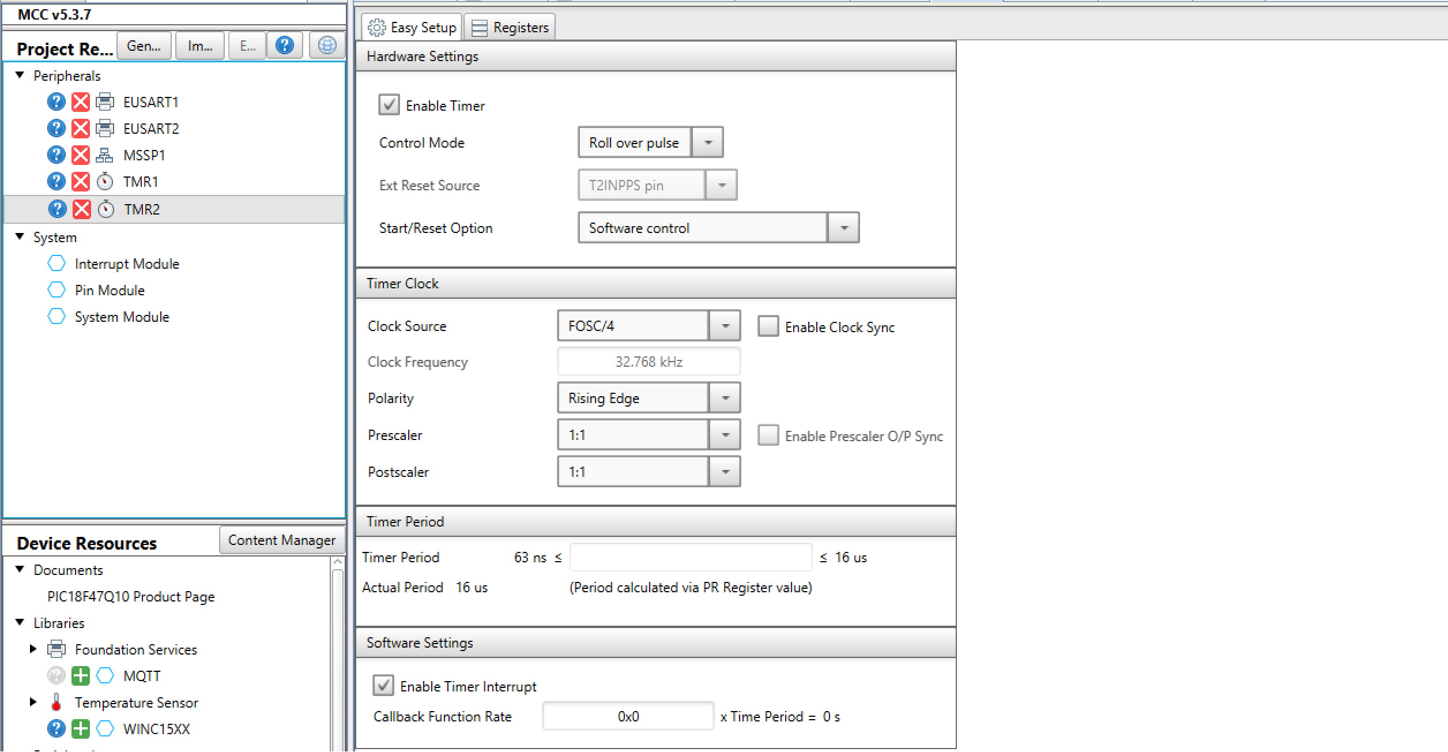
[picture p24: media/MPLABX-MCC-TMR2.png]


Timer 2
* Enable Timer
* Source: FOSC/4
* Enable Timer Interrupt
* Everything else Default

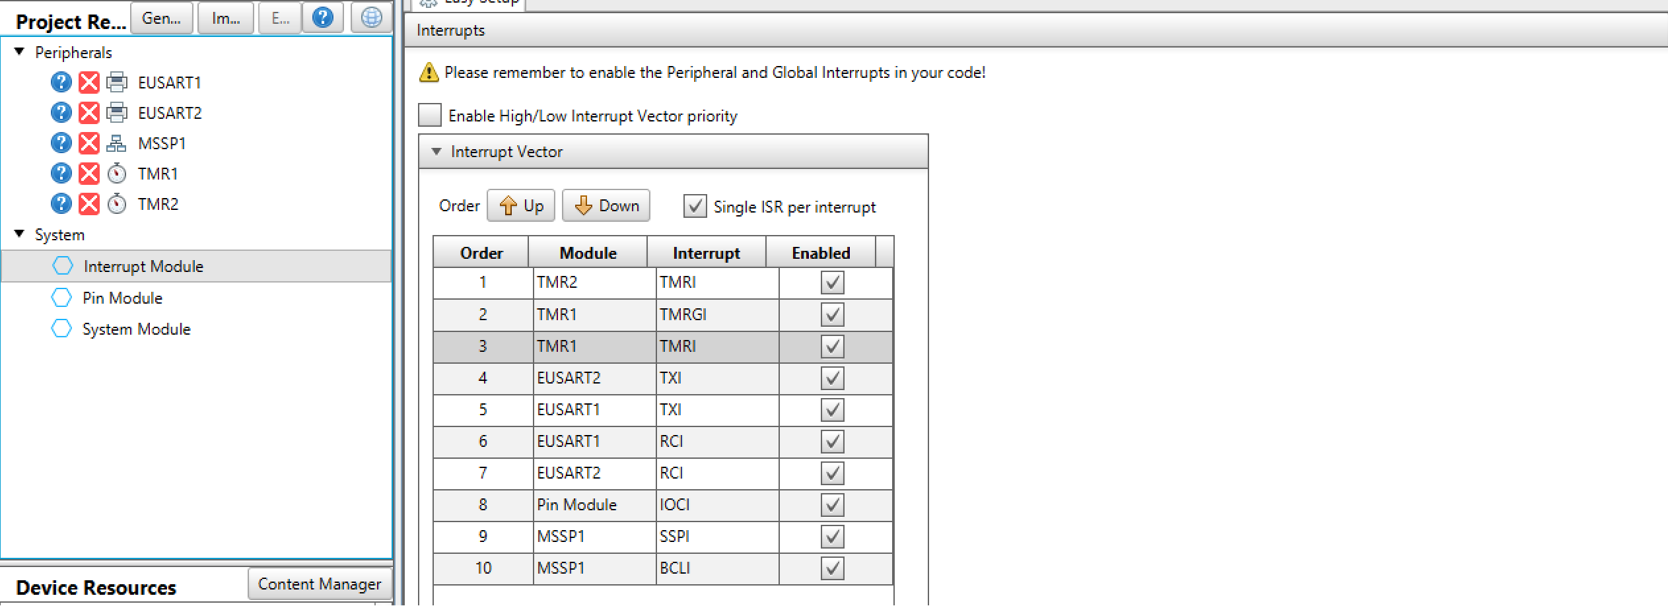
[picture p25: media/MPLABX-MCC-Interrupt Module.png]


Interrupt Module
* Make sure the Timers are on the top of Interrupt Module

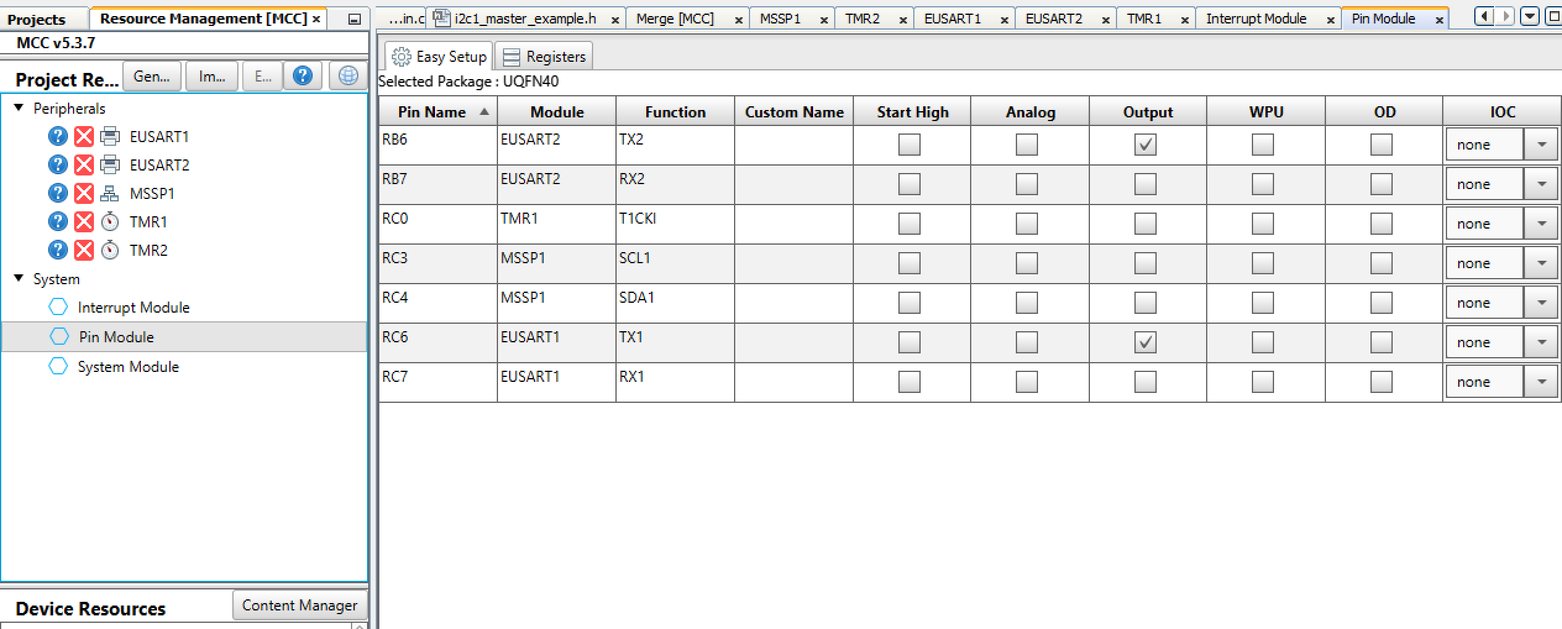
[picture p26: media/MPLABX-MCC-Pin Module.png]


Pin Module
* Only Eusart 1 and 2 are Outputs

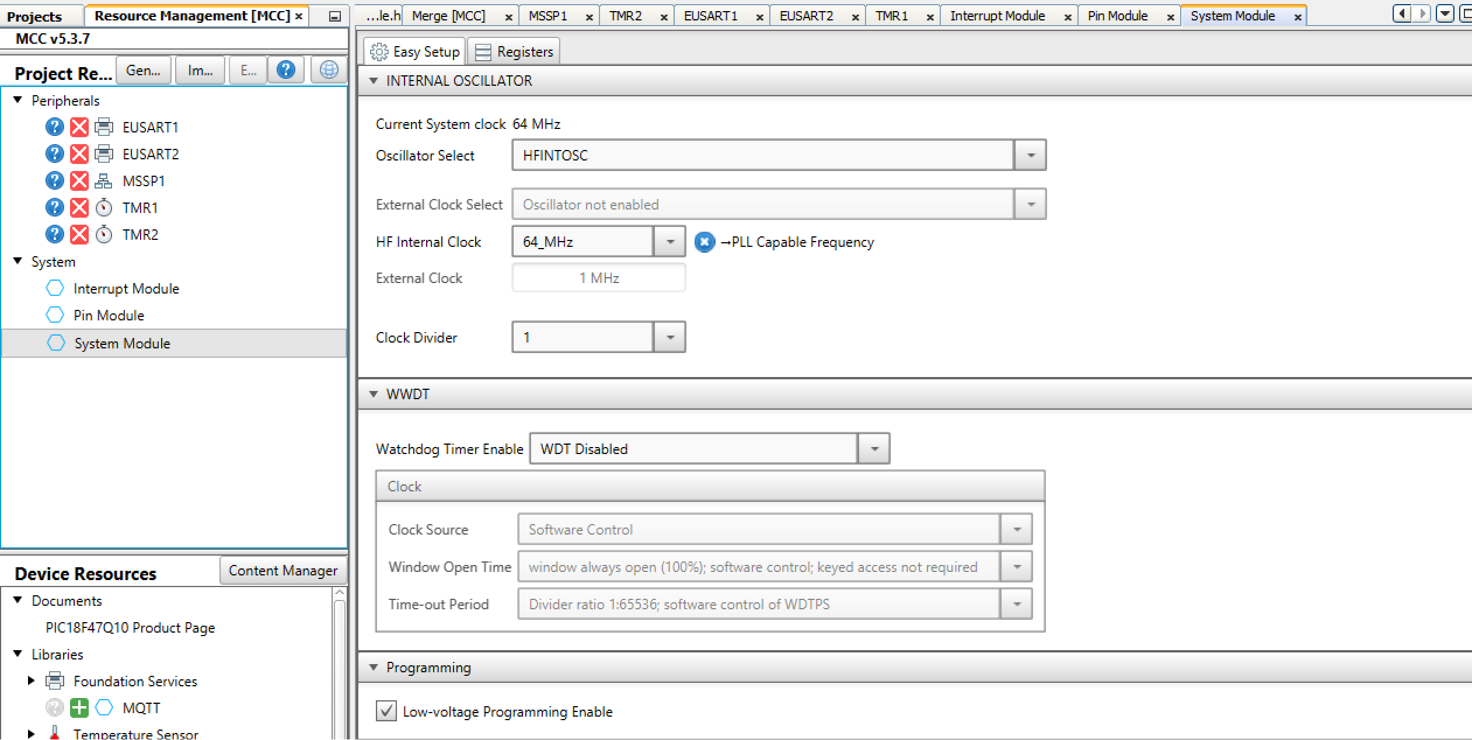
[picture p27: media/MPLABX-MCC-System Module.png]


System Module
* Oscillator Select: Make sure it is using the internal oscillator
* 64 MHz
* Watchdog Timer Disabled
* Everything else Default

# PIC Code
```C
/**
  Generated Main Source File

  Company:
    Microchip Technology Inc.

  File Name:
    main.c

  Summary:
    This is the main file generated using PIC10 / PIC12 / PIC16 / PIC18 MCUs

  Description:
    This header file provides implementations for driver APIs for all modules selected in the GUI.
    Generation Information :
        Product Revision  :  PIC10 / PIC12 / PIC16 / PIC18 MCUs - 1.81.8
        Device            :  PIC18F27J53
        Driver Version    :  2.00
*/

/*
    (c) 2018 Microchip Technology Inc. and its subsidiaries. 
    
    Subject to your compliance with these terms, you may use Microchip software and any 
    derivatives exclusively with Microchip products. It is your responsibility to comply with third party 
    license terms applicable to your use of third party software (including open source software) that 
    may accompany Microchip software.
    
    THIS SOFTWARE IS SUPPLIED BY MICROCHIP "AS IS". NO WARRANTIES, WHETHER 
    EXPRESS, IMPLIED OR STATUTORY, APPLY TO THIS SOFTWARE, INCLUDING ANY 
    IMPLIED WARRANTIES OF NON-INFRINGEMENT, MERCHANTABILITY, AND FITNESS 
    FOR A PARTICULAR PURPOSE.
    
    IN NO EVENT WILL MICROCHIP BE LIABLE FOR ANY INDIRECT, SPECIAL, PUNITIVE, 
    INCIDENTAL OR CONSEQUENTIAL LOSS, DAMAGE, COST OR EXPENSE OF ANY KIND 
    WHATSOEVER RELATED TO THE SOFTWARE, HOWEVER CAUSED, EVEN IF MICROCHIP 
    HAS BEEN ADVISED OF THE POSSIBILITY OR THE DAMAGES ARE FORESEEABLE. TO 
    THE FULLEST EXTENT ALLOWED BY LAW, MICROCHIP'S TOTAL LIABILITY ON ALL 
    CLAIMS IN ANY WAY RELATED TO THIS SOFTWARE WILL NOT EXCEED THE AMOUNT 
    OF FEES, IF ANY, THAT YOU HAVE PAID DIRECTLY TO MICROCHIP FOR THIS 
    SOFTWARE.
*/

#include "mcc_generated_files/mcc.h"
#include "mcc_generated_files/examples/i2c1_master_example.h"
#include <stdio.h>
#include <stdlib.h>
#include <math.h>
//#include "mcc_generated_files/i2c1_master.h"

#define TEMP_SENSOR_ADDRESS 0x4C
#define TEMP_SENSOR_REG 0x00

#define LIGHT_SENSOR_ADDRESS 0x10
#define LIGHT_SENSOR_REG 0x00

#define MOTOR_DRIVER_ADDRESS 0x60
#define MOTOR_DRIVER_REG 0x21

uint8_t rx2Data;
uint8_t rx1Data;

uint8_t tempValue = 0;
uint8_t tempC = 0;
uint8_t tempSign = 0; // 0 = Positive ; 1 = Negative
    
int counter = 0;
    
uint16_t lightValueRAWLux = 1;
float lightValueLux = 1;
uint16_t lightValueWhiteRAWLux = 2;
float lightValueWhiteLux = 2;
    
int MotorDir = 0;
int MotorOn = 0; // 0 = Off ; 1 = On                                              

void getTempC (uint8_t tValue, uint8_t *tC, uint8_t *tSign)
{
    //tValue = 35; // Temporal Forced value for testing
    
    if (tValue >= 128) // Negative temperature
    {
        *tSign = 1; // Negative
        *tC = 256 - tValue;
    }
    else // Positive Temperature
    {
        *tSign = 0;
        *tC = tValue;
    }
}

void TurnMotorLeft ()
{
  I2C1_Write1ByteRegister(MOTOR_DRIVER_ADDRESS, 0x01, 0x01);RA1=1; 
  
}

void TurnMotorRight()
{
  I2C1_Write1ByteRegister(MOTOR_DRIVER_ADDRESS, 0x01, 0x09);RA3=1;
  //I2C1_Write1ByteRegister(MOTOR_DRIVER_ADDRESS, 0x02, 0x00);  
  
}

float ConvertLux (uint16_t val)
{
    float gain_factor =  0.4608; //gain=1/8 and int time=100ms, max lux =  30 199 lux
    float valf = roundf(val * gain_factor);
    //lux = (((6.0135e-13 * lux - 9.3924e-9) * lux + 8.1488e-5) * lux + 1.0023) * lux;
    float valcorr = (((6.0135E-13 * valf -9.392E-9) * (valf + 8.1488E-5) * valf + 1.0023E0) * valf);
    return valcorr;
}

void EUSART1_ISR_callback(void)
{  
    // i. Call the default EUSART2 RX ISR
    EUSART1_Receive_ISR();
    
    // ii. If EUSART2 receiver has received data and is ready to be read
    if (EUSART1_is_rx_ready())
    {
        // ii.i. Read a byte from the EUSART2 buffer
        rx1Data = EUSART1_Read();
        // ii.ii. Loop until the EUSART2 transmitter is ready to accept/transmit
        while (!(EUSART2_is_tx_ready()))
            {}
        // ii.iii. Write the byte you just read to EUSART2
        EUSART2_Write(rx1Data);
        // ii.iv. Loop until EUSART2 data has been transmitted
        while (!(EUSART2_is_tx_done()))
            {}
    }
    
}

void EUSART2_ISR_callback(void){  
    // i. Call the default EUSART2 RX ISR
    EUSART2_Receive_ISR();
    
    // ii. If EUSART2 receiver has received data and is ready to be read
    if (EUSART2_is_rx_ready()) {
        // ii.i. Read a byte from the EUSART2 buffer
        rx2Data = EUSART2_Read();
        // ii.ii. Loop until the EUSART2 transmitter is ready to accept/transmit
        while (!(EUSART1_is_tx_ready()))
            {}
        // ii.iii. Write the byte you just read to EUSART2
        EUSART1_Write(rx2Data);
        // ii.iv. Loop until EUSART2 data has been transmitted
        while (!(EUSART1_is_tx_done()))
            {}
    }
}

void Motor_Controller_Toggle(void)
{
    printf("Mode: Togg Slct Ctrl\r\n");
    // Change direction if temp greater than +27 C
    if((tempSign == 0) && (tempC > 27)  &&  (MotorOn == 0))
    {

        if (MotorDir == 0) 
        {
            TurnMotorLeft();
        }
        else //motorDir == 1
        {
            TurnMotorRight();
        }

        MotorDir = !MotorDir;

        MotorOn = 1;
    }
    else
    {
        //dont spin
        if(tempC <= 27)
        {
            MotorOn = 0;
        }
    }
}

void Motor_Controller_AutoTemp(void)
{
    printf("Mode: Auto Temp Ctrl\r\n");
    // Rotate Clockwise Once if temp greater than +28 C
    if((tempSign == 0) && (tempC > 28)  &&  (MotorOn == 0))
    {

        TurnMotorLeft();
        MotorOn = 1;
        
    }
    if((tempSign == 0)  &&  (tempC <= 28)  &&  (MotorOn == 1))
    {
    // Rotate Counter Clockwise Once if temp is less than or equal to +28 C
        
        TurnMotorRight();
        MotorOn = 0;
    }
}

void Motor_Controller_AutoLight(void)
{
    printf("Mode: Auto Light Ctrl\r\n");
    //close blinds
    // Rotate Clockwise Once if light is brighter than 50000 lux 
    if((lightValueRAWLux > 50000)  &&  (MotorOn == 0))
    {

        TurnMotorLeft();
        MotorOn = 1;
        
    }
    if((lightValueRAWLux <= 50000)  &&  (MotorOn == 1))
    {
    //Open blinds
    // Rotate Counter Clockwise Once if light is less than or equal to 50000 lux 
        
        TurnMotorRight();
        MotorOn = 0;
    }
}

int main(void)
{
    SYSTEM_Initialize();
    TMR1_Initialize();
    TMR2_Initialize();
    EUSART1_Initialize();
    EUSART2_Initialize();
    TMR1_StartTimer();
    TMR2_StartTimer();
    Power_SetHigh();
    
    // If using interrupts in PIC18 High/Low Priority Mode you need to enable the Global High and Low Interrupts
    // If using interrupts in PIC Mid-Range Compatibility Mode you need to enable the Global and Peripheral Interrupts
    // Use the following macros to:

    // Enable the Global Interrupts
    INTERRUPT_GlobalInterruptEnable(); // <--
    // Enable the Peripheral Interrupts
    INTERRUPT_PeripheralInterruptEnable(); // <--

    EUSART2_SetRxInterruptHandler(EUSART2_ISR_callback);

    // Wait time to allow initialization
    __delay_ms(5000); 

    I2C1_Write2ByteRegister(LIGHT_SENSOR_ADDRESS, 0x00, 0x10);
    __delay_ms(100);
    I2C1_Write2ByteRegister(LIGHT_SENSOR_ADDRESS, 0x03, 0x00);
    __delay_ms(100);
    
    while (1)
    {
        
        //Light Sensor
        
        //I2C1_Read2ByteRegister(i2c1_address_t address, uint8_t reg)
        lightValueRAWLux = I2C1_Read2ByteRegister(LIGHT_SENSOR_ADDRESS, 0x04);
        
        lightValueWhiteRAWLux = I2C1_Read2ByteRegister(LIGHT_SENSOR_ADDRESS, 0x05);
        
        lightValueLux = ConvertLux(lightValueRAWLux);RA1=0;
        lightValueWhiteLux = ConvertLux(lightValueWhiteRAWLux);RA3=0;
        
        printf(">> Light Value #%d = %f Lux\r\n", ++counter, lightValueLux);
        printf(">> White Light Value #%d = %f Lux\r\n", counter, lightValueWhiteLux);

        //temp sensor
        tempValue = I2C1_Read1ByteRegister(TEMP_SENSOR_ADDRESS, TEMP_SENSOR_REG);
        //printf(">> Temperature Value #%d = %d \r\n", ++counter, tempValue);
        
        getTempC (tempValue, &tempC, &tempSign);
        if (tempSign == 1) // negative
        {
            printf(">> Temperature #%d = -%d C.\r\n", counter, tempC);
        }
        else // positive
        {
            printf(">> Temperature #%d = %d C.\r\n", counter, tempC);
        }

        //motor controller
        Motor_Controller_AutoTemp();
        //Motor_Controller_Toggle();
        //Motor_Controller_AutoLight();

//        if (tempC > 30)
//        {
//            Power_SetHigh();
//            __delay_ms(1000); 
//            Power_SetLow();
//        }
        
        //printf(">> MotorOn #%d = %d\r\n", counter, MotorOn);

        __delay_ms(400); // .8 second delay
    }
}
```

# ESP32 Code
```python
from mqtt_async import MQTTClient, config
import uasyncio as asyncio
import time
from machine import UART
import logging
logging.basicConfig(level=logging.DEBUG)

MAXTX = 4

# Change the following configs to suit your environment
TOPIC_PUB = 'EGR314/Team305/DR'
TOPIC_SUB = 'EGR314/Team305/DR'
config.server = 'egr3x4.ddns.net' # can also be a hostname
config.ssid     = 'photon'
config.wifi_pw  = 'particle'

uart = UART(2, 9600,tx=17,rx=16)
uart.init(9600, bits=8, parity=None, stop=1,flow=0) # init with given parameters

async def receiver():
    b = b''
    sreader = asyncio.StreamReader(uart)
    while True:
        res = await sreader.read(1)
        if res==b'\r':
            await client.publish(TOPIC_PUB, b, qos=1)
            print('published', b)
            b = b''
        else:
            b+=res

def callback(topic, msg, retained, qos):
    print('callback',topic, msg, retained, qos)
    while (not not msg):
        
        uart.write(msg[:MAXTX])
        time.sleep(.01)
        msg = msg[MAXTX:]

    uart.write('\r\n')
    time.sleep(.01)
  
async def conn_callback(client): await client.subscribe(TOPIC_SUB, 1)

async def main(client):
    await client.connect()
    asyncio.create_task(receiver())
    while True:
        await asyncio.sleep(1)

config.subs_cb = callback
config.connect_coro = conn_callback

client = MQTTClient(config)
loop = asyncio.get_event_loop()
loop.run_until_complete(main(client)) 
```

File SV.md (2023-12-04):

---
title: Home 
---
 
# System Verification

One of the last steps for our project is to make sure that each subsystem we created individually can be connected together. This ensures that everyone's subsystem works, and that we worked cohesively as a team. This process involved wiring every system together and rigorously testing every aspect.

For our first attempt, we were able to get it powered up with base subsystems working. This included our voltage regulator and our microcontroller.
{% include youtube.html id="7ClaZi1Gy6I" %}

Although not much, it was a start, and after some further debugging we were able to get the microcontroller to program successfully, as well as verify that voltage was indeed reaching other sybsystems.
{% include youtube.html id="53aBljYX6Nw" %}

After several hours of further debugging, we were able to establish that the wireless communication and temperature sensors were working. 
{% include youtube.html id="ZHouU2MR2r4" %}

Next, we were able to utilize the same technique developed to correct the temperature sensor on the light sensor. This allowe us to test our motor, since it was dependant on the other sensors.
{% include youtube.html id="FDRjx8eOcD0" %}

With everything working correctly, we shot a short video documenting the final verification. This was so that we have proof that it worked in case something happened to the main system before we could finally present. Showing that everything worked correctly, here is our final verification.
{% include youtube.html id="lCwTpInNI6Q" %}

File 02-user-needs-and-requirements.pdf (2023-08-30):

## User Needs, Benchmarking and Product Requirements

Team 305: Nick, Jack, Diego and Uriah

Product 1: Emporia Vue: Gen 2 with 16 sensors

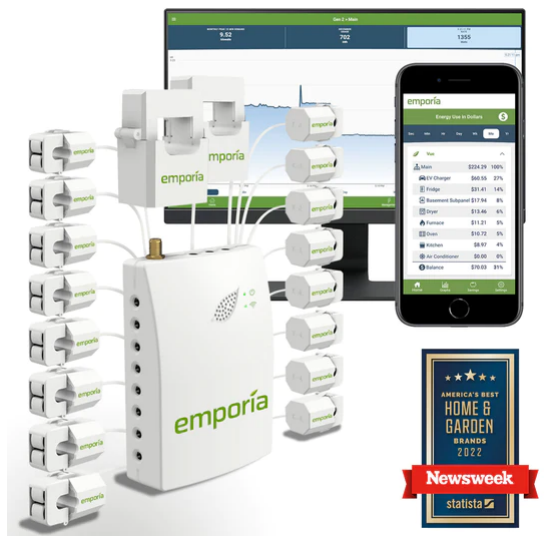
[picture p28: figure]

Link: emporiaenergy.com (https://shop.emporiaenergy.com/products/gen-2-emporia-vue-with-16-sensors-bundle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)

Price: $164.99
Vendor: Emporia
Description: Home Energy Monitor

Positive reviews:
1. Easy to use - Latent
2. Simple to install - Latent
3. Does what it says it does - Explicit

Negative reviews:
1. Cyber Safety concerns due to wifi connection with low security - Explicit
2. Doesn’t give much functionality info - Latent
3. Only works for specific setups (Isn’t universal) - Explicit
4. Interface isn't great - Latent
5. Poor wifi connection - Latent

Product 2: SwitchBot Curtain Smart Electric Motor

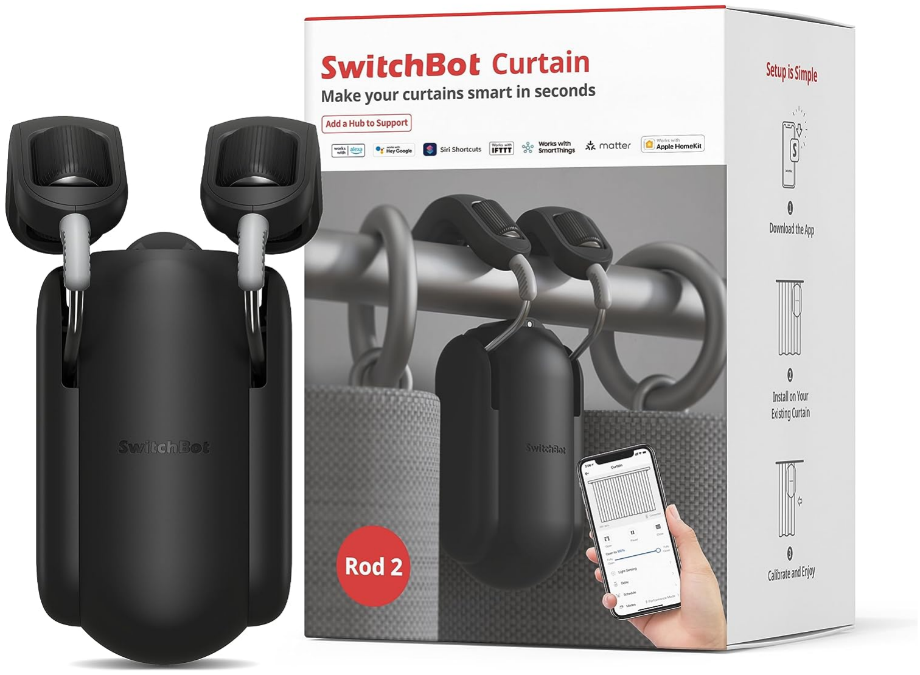
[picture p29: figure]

Link: Amazon.com (https://www.amazon.com/Upgraded-Version-SwitchBot-Curtain-Electric/dp/B09Y5YW8FJ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)

Price: $84.99
Vendor: Amazon
Description: Curtain motor

Positive reviews:
1. Easy physical setup - Latent
2. Easy digital setup/ programming - Latent
3. Works exactly as advertised - Explicit
4. Isn’t in line of sight (non-invasive) - Explicit
5. Works for any size curtains - Latent

Negative reviews:
1. A little too noisy for comfort - Explicit
2. Doesn’t work well on non-smooth curtain beams - Explicit
3. Requires occasional calibration, sometimes is often needed - Latent
4. Too expensive for what you get - Latent
5. Short battery life - Explicit

Product 3: Rechargeable Wireless Tubular Roller Shade Motor Kit

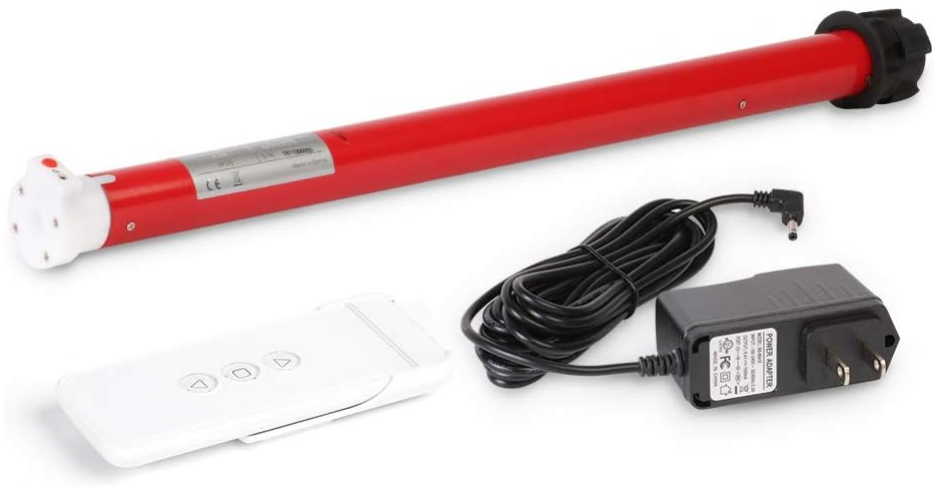
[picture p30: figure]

Link: Amazon.com (https://www.amazon.com/Rechargeable-Wireless-Tubular-Motorized-Electric/dp/B074TKQ8DJ)

Price: $92.99
Vendor: Amazon
Description: Curtain motor

Positive reviews:
1. Very good price for what it is (cost effective) - Latent
2. Good setup/use instructions - Latent
3. Works well - Explicit
4. Great adaptability in the sense of works with pretty much any shade curtain -Explicit
5. Great customer support - Latent

Negative reviews:
1. Requires some DIY experience - Explicit
2. Bad battery life (requires upgrades) - Explicit
3. Requires some programming experience to unlock full functionality - Latent

Product 4: SwitchBot Smart Motorized Blinds Kit


Link: Amazon.com (https://www.amazon.com/SwitchBot-Smart-Motorized-Blinds-Kit/dp/B0BNHQJ95L)

Price: $189.99
Vendor: Amazon
Description: Motorized Blinds.

Positive reviews:
1. Cost effective smart blinds - Latent
2. Nice user-friendly Interface - Latent
3. Easily programmable - Explicit
4. Aesthetically pleasing (is visible) - Latent
5. Easy Installation - Explicit
6. Compatible with Apple products - Explicit

Negative reviews:
1. Calibration can be a bit tricky - Latent
2. Short lifespan due to mostly being made of plastic - Explicit
3. Bad customer service - Latent
4. Isn’t always reliable and sometimes glitches or fails a little - Latent

Product 5: Dusk to Dawn A19 Outdoor LED Light Bulbs


Link: Amazon.com (https://www.amazon.com/Equivalent-Automatic-Daylight-Photocell-Security/dp/B08LDNG9T2?s=industrial)

Price: $15.99
Vendor: Amazon
Description: Sunlight sensor bulbs

Positive reviews:
1. “Efficient solution” to making sure lights are on at night and off during day -Explicit
2. Extremely easy installation (is the same as a regular light bulb) - Explicit
3. Shines bright - Explicit
4. Works as advertised - Latent
5. Works reliably and doesn't fail - Explicit

Negative reviews:
1. Relatively short lifespan - Explicit
2. Low wattage (incompatible with some home systems) - Explicit
3. Doesn’t works outside because it isn't waterproof - Explicit
4. They come in bad packaging and often get damaged during shipping - Explicit

### Jamboards:



### Organized:

User- Preferences


Marketing


Ranking


### Develop Requirements:

Introduction

Pretty much every house or apartment has windows and other home appliances that can be redundant in moving, changing, or turning off and on. This problem leaves room for technological solutions to automate and facilitate all those redundant activities. That being said, there is a market for products that have light-sensing capabilities which can in turn help users utilize these devices to adapt their systems to different times of the day and certain conditions when the appliances should be on or off. We have a solution that can utilize different sensors and motors to fully automate redundant household functions that will elevate the quality of life for the users .

Objectives

Our main objective is to design and develop a simple yet efficient home automation system. It must include at least one motor that is activated through a sensor as well as another sensor and a reliable power supply, all while the design and functionality satisfies the user and stakeholder needs gathered in earlier research.

Use case #1
Uriah lives in a large house in the middle of the Arizona desert and he needs to close the blinds in his house when he leaves or else the whole house heats up too much. It takes him way too long to constantly go around the whole house individually, closing and opening all the blinds. He decides to invest in a home automation system that can sense the temperature and brightness to open or close all the blinds for him. He can now save a lot of effort and time by not having to worry about whether his house will be too dark or too hot due to the outside temperature and brightness.

Use case #2
Jack lives in a small apartment with a couple of windows. However, he is always extremely busy and can’t afford to waste time with simple things such as opening or closing the blinds for sunlight into his apartment, which also doubles as his office. He decides to get a home automation system to automate and control the amount of sunlight he receives without having to stop working. Jack can now live in a more efficient manner.

Aspects

### 1. Product Design

1.1. Design must be efficient and easy to understand/use
1.2. Has to be aesthetically pleasing
1.3. Needs to be durable and built for longevity after constant use
1.4. Needs to be heat and solar deterioration resistant

### 2. Software/ Functionality

2.1. System will utilize a variety of sensors to monitor environmental conditions
2.2. Has Wi-Fi functionality
2.3. Must have customizable programming

### 3. Interactivity/ User experience

3.1. Installation must be simple without much modification needed
3.2. Maintenance should be quick and easy or non-existent
3.3. User interface needs to be straightforward

### 4. Customization

4.1. The user should be able to adjust the sensitivity and timing of the sensors
4.2. The user should be able to monitor the status of the devices
4.3. The user should be able to modify the components as needed

### 5. Manufacturing

5.1. Materials should be good quality while also being cost efficient
5.2. Material will be durable and have longevity

### 6. Safety

6.1. Shouldn’t have any sharp features to prevent unnecessary injury
6.2. Shouldn’t run on abnormally high power
6.3. Needs instructions on how to operate safely
6.4. Shouldn’t be made of materials that are potentially hazardous

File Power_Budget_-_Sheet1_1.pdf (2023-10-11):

| Peak Sustained Current (mA) | Nominal Voltage | Max watts
PIC18 | 50 | 3.3 | 0.165
ESP32 | 280 | 3.3 | 0.924
Motor | 1000 | 12 | 12
Motor Driver | 5 | 3.3 | 0.0165
Light Sensor | 0.05 | 3.3 | 0.000165
Temp Sensor | 0.2 | 3.3 | 0.00066
Total | Total
| 1335.25 | | 13.106325
12V 1.5A Fuse | The motor can use upto 1A of current at fully speed so a 1.5A fuse
| will be sufficient to let it run safely at full speed and still protect from shorts. The rest of the low voltage components will draw less than 350mA typically with the current parts, so a 500mA fuse will be sufficient as wellas allow for us to use a few more low curren divices in the future as well

3.3V 500mA Fuse

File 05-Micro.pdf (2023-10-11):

Design Considerations | Team Project-Specific Requirements | PIC Option 1 PIC18F27J53-I /SO | PIC Option 2 PIC18F27Q10 | PIC Option 3
GPIO Pin # | 6 | 28 | 24 | 18
Built in Analog to Digital Converter. # | 2 | 2 | 2 | 2
Built-in Hardware PWM. # | 2 | 2 | 2 | 2
Built in I2C or SPI. # | 2 | 2, 2 | 2, 2 | 2, 2
Built in UART. # | 2 | 2 | 1 | 2
Microcontroller Considerations | PIC Option 1 | PIC Option 2 PIC18F27Q10 | PIC Option 3
Part Number | PIC18F27j53-I/SO | PIC18F27Q10 | PIC18F14Q40-I/SS
Link to product page | Link (https://www.microchipdirect.com/product/PIC18F27J53-I%2FSO) | Product Link (https://www.microchip.com/en-us/product/PIC18F27Q10) | Link (https://www.digikey.com/en/products/detail/microchip-technology/PIC18F14Q40-I-SS/13534530)
Link to Data Sheet | Data Sheet (https://www.microchip.com/en-us/product/PIC18F27J53) | Data Sheet (https://ww1.microchip.com/downloads/aemDocuments/documents/MCU08/ProductDocuments/DataSheets/PIC18F27-47Q10-Data-Sheet-40002043E.pdf) | Data Sheet (http://ww1.microchip.com/downloads/en/DeviceDoc/PIC18F04-05-14-15-Q40-1420-Pin-Low-Power-High-Performance-Microcontroller-With-XLP-Technology-Data-Sheet-40002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)
Link to Application Notes | Notes (https://www.microchip.com/en-us/application-notes/tb3237) | Application Notes (https://www.microchip.com/en-us/application-notes/tb3237) | Application Notes
Link to Code Examples | Code Ex. | Code Ex. (https://github.com/microchip-pic-avr-examples?utf8=%E2%9C%93&q=pic18f47q10&type=&language=) | Code Ex.
Link to External | Resources | Resources | Resources

Resources

Production Unit
Cost
$5.24 | $1.62 | $1.23
Supply Voltage Range | 1.8 - 9 V | 1.8 - 5.5 V | 1.8 - 5.5 V
Absolute Max Current | 350 mA | 350 mA | 350 mA
Max GPIO Pin Current | 250 mA | 250 mA | 250 mA
8-bit or 16-bit | 16-bit | 16 bit | 8bit
Footprints | Surface Mount | Surface Mount | Surface Mount
Supports External Interrupts | yes | Yes | yes
In-System Programming Capability and Type | yes | Yes | yes

Programming
Hardware and
Cost
$5.24 | $1.62 | $1.23
Works with MPLAB X IDE | yes | Yes | yes
Works with Microchip Code Configurator | yes | Yes | yes

Overall Pros | 1. Exceeds all requirements 2. Powerful for what we need | 1. Meets all the necessary requirements 2. Inexpensive | 1. Meets all requirements 2. Is cheap
Overall Cons | 1. Not cheap. | 1. Doesn’t have much room for adding potential extra components 2. There isn’t much external info on it | 1. Pins are somewhat small.
Ranking | 1 | 3 | 2

Final Choice: We are choosing option 1 because it fits best for our project. Option 3 does not meet all our requirements, and 2 is an inadequate version of 1. Thus, option 1 is the preferable choice between these 3 options.

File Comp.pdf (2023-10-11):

Team 305 - Component Selection

Component: Temperature Sensor

Choices:
Name: TC74A4-3.3VCTTR Price: $1.15 Link: Digikey (https://www.digikey.com/en/products/detail/microchip-technology/TC74A4-3-3VCTTR/443268) | Pros: ● Surface Mount ● Cheap ● Reliable seller ● Datasheet included ● Fast shipping ● Included in class | Cons: ● Small part


Name: STLM75M2F Price: $1.24 Link: Digikey (https://www.digikey.com/en/products/detail/stmicroelectronics/STLM75M2F/1657333) | Pros: ● Surface Mount ● Cheap ● Reliable seller ● Datasheet included | Cons: ● Long shipping time ● Very small part


Name: STS21 Price: $3.36 Link: Digikey (https://www.digikey.com/en/products/detail/sensirion-ag/STS21/5872256) | Pros: ● Surface Mount ● Reliable seller ● Datasheet included | Cons: ● Long shipping time ● Impossibly small part - Unable to work with ● Expensive

Choice: TC74A4-3.3VCTTR

Reason: Since it was the part given in class for an ICC, it will be easier to utilize than other components online. Given that it’s used by the students and professor, there will be an abundance of help available with this part should we face any hardship with it. Also, given it’s cheap and ships fairly quickly, we will have more than enough of them for our project.

Component: Motor Controller

Choices:
Name: IFX9201SGAUMA1 Price: $3.79 Link: Digikey (https://www.digikey.com/en/products/detail/infineon-technologies/IFX9201SGAUMA1/5415542) | Pros: ● Very good ● Reliable seller ● Used in class ● Fast shipping | Cons: ● Expensive


Name: TMC2160A-TA-T Price: $6.21 Link: Digikey (https://www.digikey.com/en/products/detail/trinamic-motion-control-gmbh/TMC2160A-TA-T/11306896) | Pros: ● Will not be over loaded with its 20A max current draw ● Will not be shorted out with its 50V max supply voltage | Cons: ● More expensive ● Long shipping time
Name: IMC101TT038XUMA1 | Pros: ● Cheap | Cons: ● Way too many pins

Price: $3.35
Link: Digikey (https://www.digikey.com/en/products/detail/infineon-technologies/IMC101TT038XUMA1/8627107)
- Very diverse use | ● Pins extremely small ● Long shipping time

Choice: IFX9201SGAUMA1

Reason: Since it is the device we used in class, there is great support for this device. It also functions for what we desire.

Component: Motor

Choices:
Name:12V DC Reversible Gearhead Motor Price: $2.25 Each Link: Jameco (https://www.jameco.com/z/MD3B-14280-R-Nichibo-Taiwan-12V-DC-Reversible-Gear-Head-Motor-5214-RPM-180-1-30-RPM_2197476.html) | Pros: ● Small Gear Case ● Inexpensive | Cons: ● Lower RPM ● Short motor shaft
Name:DCM-1023 | Pros: ● Low RPM ● High Torque ● Fast shipping ● Durable | Cons: ● Large and bulky ● Expensive

Price: $85.00 Link: Digikey (https://www.digikey.com/en/products/detail/multi-products-company-inc/DCM-1023/15668252)


Name: 1081000006 Price: $2.50 Link: Digikey (https://www.digikey.com/en/products/detail/seeed-technology-co-ltd/108100006/5488027) | Pros: ● Super cheap ● Very small | Cons: ● Very high RPM ● Long ship time

Choice: 12V DC Reversible Gearhead Motor

Reason: It is small, compact, and cheap. Perfect for our project where we need a small motor.

Component: Light Sensor

Choices:
Name:VEML7700-TT | Pros: | Cons:

Price: $1.88 Link: Digikey (https://www.digikey.com/en/products/detail/vishay-semiconductor-opto-division/VEML7700-TT/6210690) | ● Very fast shipping ● Cheap ● I2C compatible | ● Small part ● Needs subsequent system for easier readings
Name: VEML7700-TR Price: $1.88 Link: Digikey (https://www.digikey.com/en/products/detail/vishay-semiconductor-opto-division/VEML7700-TR/5820243) | Pros: ● Very fast shipping ● Cheap ● I2C compatible | Cons: ● Small part ● Needs subsequent system for easier readings


Name: RPR-0521RS Price: $1.95 Link: Digikey (https://www.digikey.com/en/products/detail/rohm-semiconductor/RPR-0521RS/5981561) | Pros: ● I2C Compatible ● Cheap | Cons: ● Long shipping time ● Pins are barely accessible.

Choice: VEML7700-TT/TR depending on tolerances for our project. Both have the same electrical works but the shape of the packaging and pin orientation differ a bit. Both are readily available and in stock at a low price. They do everything we need but can be made better with an additional subcircuit.

Reason: We need to communicate with the professor about the potential use of a daughter board for this part. Choice 1 is the primary option though.

Component: Pic Microcontroller

Choice: Chosen in Microcontroller Selection Assignment.

Component: ESP32

Choice: Given

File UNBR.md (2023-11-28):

---
title: Home 
---
 
# User Needs, Benchmarking, and Requirements  
  When deciding upon which ideals are most important to the customer, we utilized a process similar to reverse engineering. We first collected multiple items similar to our desired project idea, and researched information on them. This allowed us to discover many quailities about the products, such as price, vendor, compatibilities, mutliple usages, durability and many positive and negative reviews about each one. Sorting through all of this data would have been unusually difficult without liositng every detail on little notes. This allowed us to move to our next process: Jamboards.
  
  A Jamboard is a sheet of notes with every idea, note, ideals, specifications, etc., about a given topic. It is similar to a whiteboard with dozens of post-it notes all across it. Digitally, we wrote down as many notes we could think of or find in the user reviews of similar products. This created a mess for us to sort through. We then organized them by what category they fit into. Project requirements, user wants, user needs, marketing, etc. Next we eliminated any duplicate notes, or combined any too similar into a broader subject. After this, we rated each note based on how important it is to us as well as the customer, thus producing our main user needs. 

  Jamboards
  image caption
  image caption
  image caption
 
* [Appendix B: User Needs, Benchmarking, and Requirements](/02-user-needs-and-requirements.pdf)

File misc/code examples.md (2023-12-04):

---
title: Home 
---
 
# Website Coding Examples
  
* [Example of link text in RAW](/MicroSelect)

* [Test subpage beta](/T-O) links to a download

* [Test subpage](/T-O.md) works. This one links to a subpage. Make sure it includes .md at the end

* [Example of external link embed in RAW](https://doadsheets/d/1ZWJujIUSddGSwfPPaxeSsj4ZDpHQYlIZ/edit#gid=2120733341)

* Image by link example
  
image caption

"And here's to you, <span style="background-color:green">Mrs. Robinson</span>, Jesus loves you more than you will know."
<div style="background-color:rgba(0, 0, 0, 0.0470588); text-align:center; vertical-align: middle; padding:40px 0;">
<a href="/donate">DONATE</a>
</div>

<div style="background-color:rgba(0, 0, 0, 0.0470588); text-align:center; vertical-align: middle; padding:40px 0; margin-top:30px">
<a href="/blog">VIEW THE BLOG</a>
</div>

{% include youtube.html id="JLMbpiywVxQ" %}

{% include youtube.html id="dQw4w9WgXcQ" %}


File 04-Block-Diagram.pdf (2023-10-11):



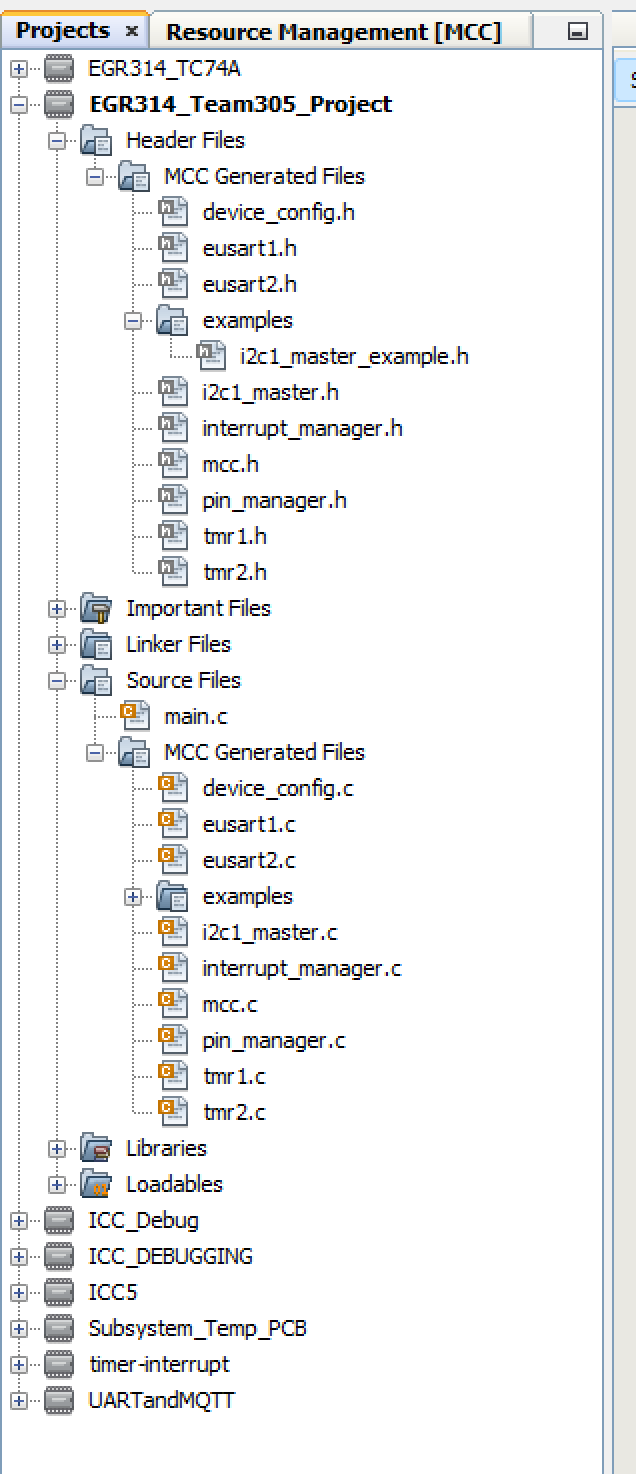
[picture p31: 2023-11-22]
media/MPLABX-Files view.png

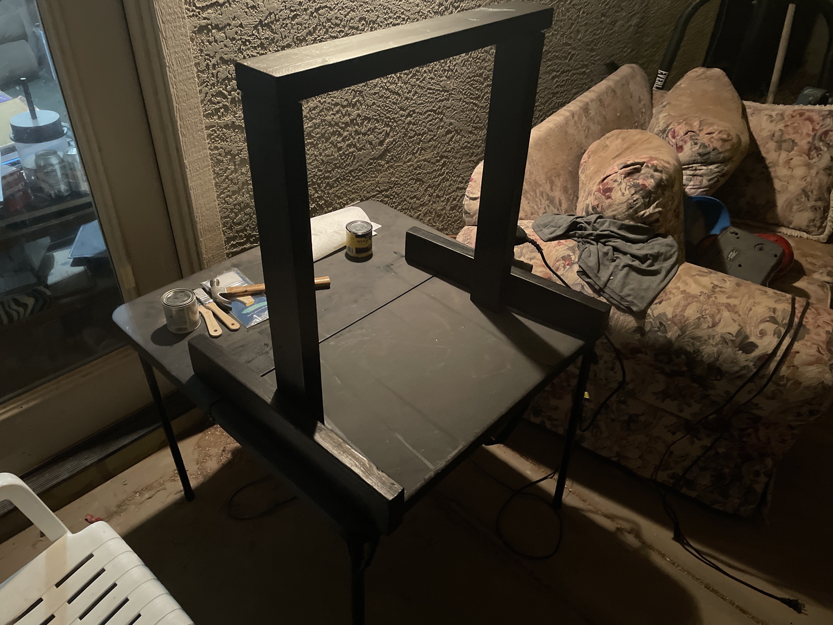
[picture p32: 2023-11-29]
media/Framework 2.jpg

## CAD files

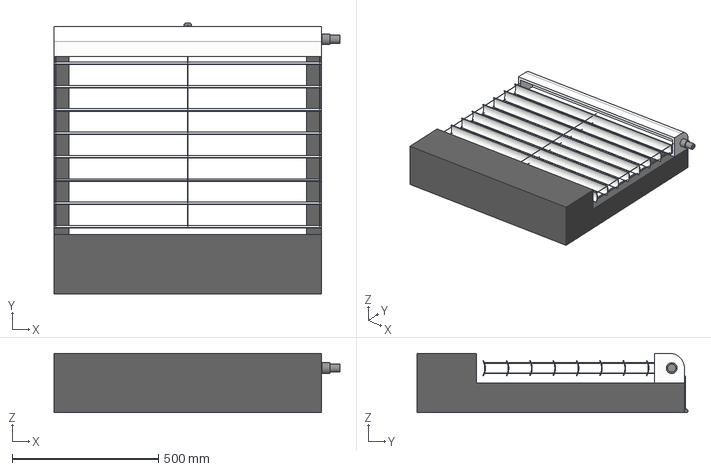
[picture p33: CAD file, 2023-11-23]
cad files/EGR314_Team_305_Blinds_Demo.step
977.7 x 927.1 x 203.2 mm

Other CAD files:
cad files/EGR314_Team_305_Blinds_Demo_.f3z

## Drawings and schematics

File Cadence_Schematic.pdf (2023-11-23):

3.3V | PICkit 4 Header Pins R1

# PIC18F27J53-I/SO

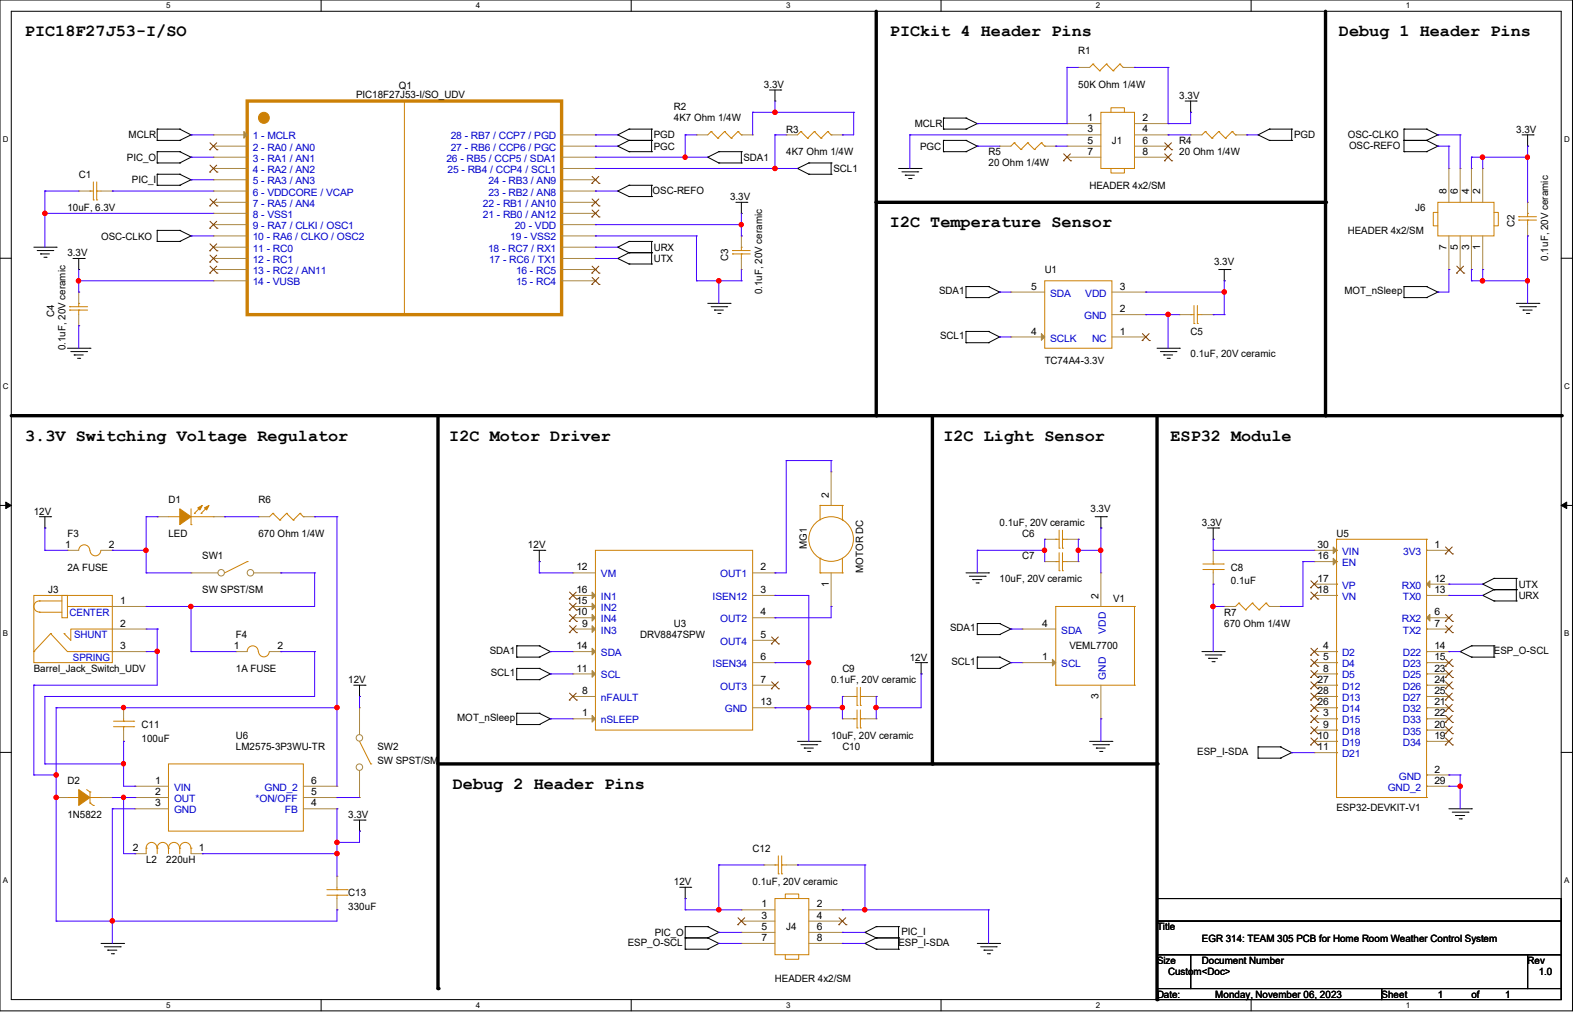
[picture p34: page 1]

U1 TC74A4-3.3VNC 1 GND 2 VDD 3 SCLK 4 SDA 5 SW1 SW SPST/SM

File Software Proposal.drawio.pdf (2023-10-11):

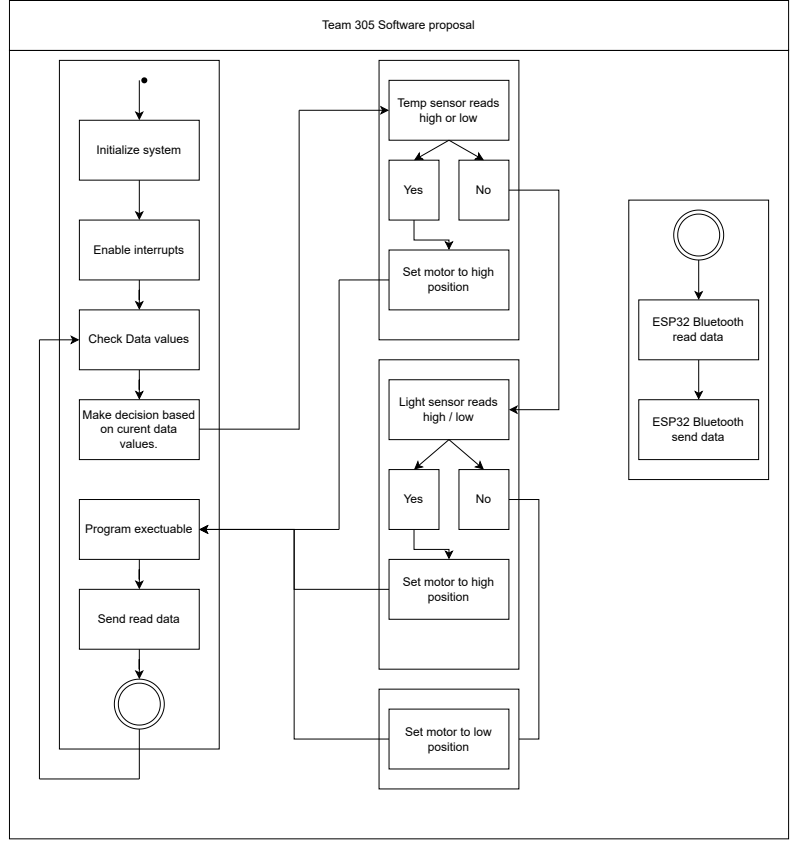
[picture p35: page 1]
Initialize system; Enable interrupts; Program exectuable; Yes; ESP32 Bluetooth send data; ESP32 Bluetooth read data

Team 305 Software proposal

Temp sensor reads
high or low

Set motor to high
position

Check Data values

Light sensor reads
high / low

Make decision based
on curent data
values.

Send read data

Set motor to low

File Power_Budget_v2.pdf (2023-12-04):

# Power Budget v2

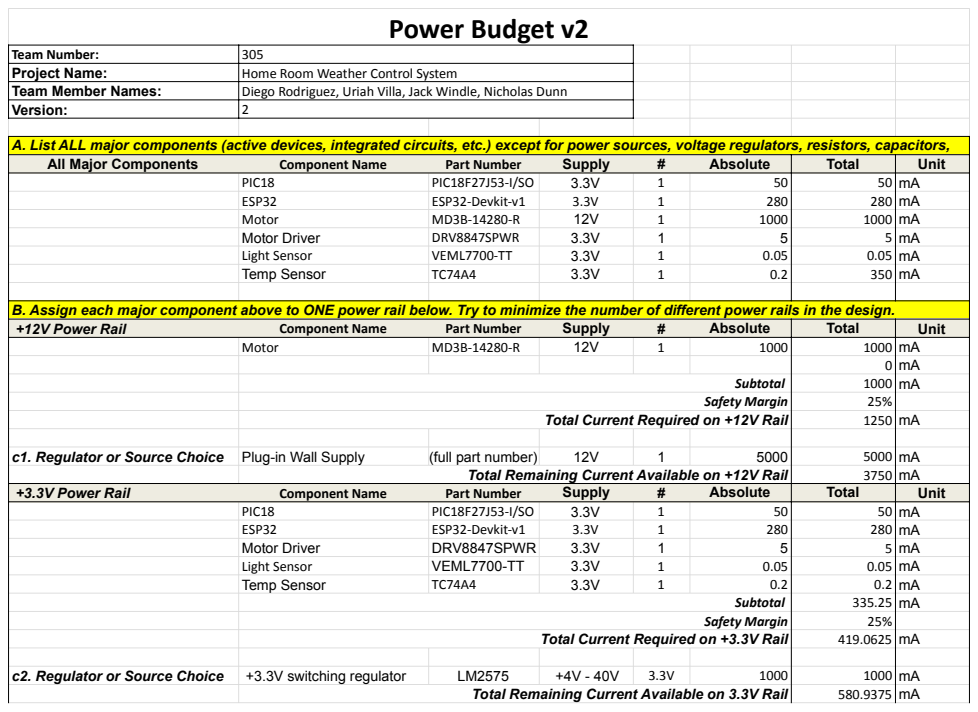
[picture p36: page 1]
PIC18; PIC18F27J53-I/SO; ESP32; ESP32-Devkit-v1; Motor Driver; DRV8847SPWR; Light Sensor; VEML7700-TT; Temp Sensor; Subtotal; Safety Margin; Total Current Required on +3.3V Rail; c2. Regulator or Source Choice; +3.3V switching regulator; Total Remaining Current Available on 3.3V Rail

Team Number: | 305
Project Name: | Home Room Weather Control System
Team Member Names: | Diego Rodriguez, Uriah Villa, Jack Windle, Nicholas Dunn
Version: | 2

A. List ALL major components (active devices, integrated circuits, etc.) except for power sources, voltage regulators, resistors, capacitors,

All Major Components Component Name Part Number Supply # Absolute | Total | Unit

PIC18 PIC18F27J53-I/SO 3.3V 1 50 ESP32 ESP32-Devkit-v1 3.3V 1 280 Motor MD3B-14280-R 12V 1 1000 Motor Driver DRV8847SPWR 3.3V 1 5 Light Sensor VEML7700-TT 3.3V 1 0.05 Temp Sensor TC74A4 3.3V 1 0.2 | 50 280 1000 5 0.05 350 | mA mA mA

B. Assign each major component above to ONE power rail below. Try to minimize the number of different power rails in the design.

+12V Power Rail Component Name Part Number Supply # Absolute | Total | Unit
Motor MD3B-14280-R 12V 1 1000 Subtotal Safety Margin Total Current Required on +12V Rail c1. Regulator or Source Choice Plug-in Wall Supply (full part number) 12V 1 5000 Total Remaining Current Available on +12V Rail | 1000 0 1000 25% 1250 5000 3750 | mA mA mA

+3.3V Power Rail Component Name Part Number Supply # Absolute | Total | Unit

C. For each power rail above, select a specific voltage regulator using the same process as for major component selection. Confirm that the
D. Select a specific external power source (wall supply or battery) for your system, and confirm that it can supply all of the regulators for all
External Power Source 1 Component Name Part Number Supply Output Absolute | Total | Unit
Power Source 1 Selection | Plug-in Wall Supply | (full part number) | 110VAC | +12V | 5000 | 5000 | mA
Power Rails Connected to External Power Source 1 | | | | | | 0 | mA
| | | | | | 0 | mA
| +3.3V switching regulator | LM2575 | +4V - 40V | 3.3V | 1000 | 1000 | mA
| Total Remaining Current Available on External Power Source 1 | | | | | 4000 | mA
E. Calculate Battery Life (if applicable). For each battery, also check the worst-case lifetime of the battery by
Component Name Part Number Supply Capacity | Required
N/A | N/A | N/A | N/A | N/A | N/A
| Battery Life | N/A | hours
Notes
External Supply Voltage should be determined by the dropout voltage for highest-voltage regulator (e.g., +14V for a +12V regulator). If you have multiple units in your design (e.g., a base unit and remote unit) then you need a separate power budget for each unit
